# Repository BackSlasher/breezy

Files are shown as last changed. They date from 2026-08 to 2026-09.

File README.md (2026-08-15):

# Breezy

ESP32 smart-home component for my air conditioner, physically sitting between the HVAC controller and its LCD control panel.

The kit here is a **USP 5010** — controller plus LCD panel (the panel is
marked USP5010BE). If that is what you have, the protocol docs and the
ESPHome components in this repo should work as-is.

Smart-home capability achieved with ESPHome (flashed via USB, OTA available).  
Reads are done by intercepting SPI updates from the AC to the panel.  
Writes are done by emulating IR remote commands.

## In this repo
1. [pcb](pcb/): Board schematics, JLCPCB-ready
2. [esphome/components](esphome/components/): Custom ESPHome components ([example config](esphome/breezy_v4.yaml))
3. [case](case/): scad files for a small case/box for the pcb
4. [docs](docs/): the protocol specs — [the bus](docs/PROTOCOL_BUS.md) and
   [the IR command language](docs/PROTOCOL_IR.md) — plus the working notes
   behind them, and [some photos](docs/photos.md).

## Wiring

Physical wiring:
1. JST 6-wire cable (only 5 actual wires) to AC unit
2. JST 6-wire cable (only 5 actual wires) to LCD panel
3. 220v in (L/N screw terminals) for powering the ESP32 (5v from SPI is weak)

JST wiring is 5v (5v+, gnd, SPI data, SPI clock, IR)

The ESP32 itself is a socketed 38-pin ESP32-WROOM-32 DevKitC-style module
(2×19 headers) — not included on the PCB, plug in your own.

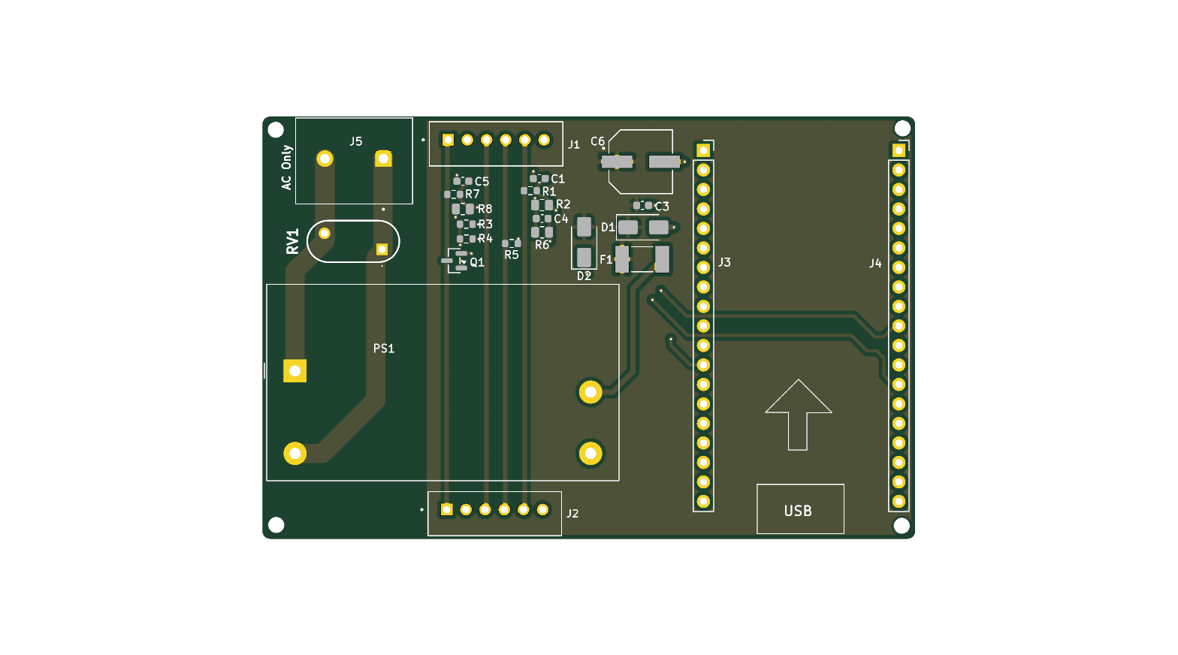
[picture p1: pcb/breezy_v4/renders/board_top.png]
board top


## The protocol, briefly

### Read
The HVAC and its panel talk over a clocked two-wire bus, ~33 ms per cycle.
There are exactly two frames on it:

- a **36-bit LCD status poll** — the controller opens it and goes quiet, and
  the panel answers *inside the same frame* by pulling bits low (the line is
  wired-AND). I don't decode what the panel says; I have no use for it.
- a **76-bit controller status** — the complete unit state, and the one I
  read: power, mode, set temperature, room temperature, fan speed, and
  whether the compressor is actually running right now.

Every bit of the controller status is located and its encoding known, so a
frame can be generated from scratch and checked against the two checksums it
carries. Two flag bits are still unexplained — I know where they are and
when they fire, just not what they mean; one is probably the panel's
backlight. Full field map in [`docs/PROTOCOL_BUS.md`](docs/PROTOCOL_BUS.md).

### Write

The controller is receiving IR commands from a remote via the LCD panel.
The panel holds an IR receiver, demodulates the output and sends the binary on a dedicated wire to the controller, which we can both intercept and send our own.

The IR protocol is reverse engineered completely: any mode, temperature and
fan speed can be composed from scratch, including power-on, which carries the
target state inside the toggle so the unit wakes straight into it. Full spec
in [`docs/PROTOCOL_IR.md`](docs/PROTOCOL_IR.md).

Two things about it are worth knowing before you read anything else:

- **The symbol spelling is the code.** Three of the four pulse shapes mean
  "1", so the same bits can be spelled several ways — and the unit treats
  different spellings as *different commands*.  
  When encoding / decoding, take care to note the length of each part of the pulse (the "on" and the "off" afterwards).
- **24 °C and 25 °C share a temperature byte** and are told apart only by the
  frame being one bit shorter. That one confused me for a while.

## Short version history

Bus pirate worked out of the box for reading, and Arduino R4 bitbanging was enough for writing.  
When moving to dedicated ESP32+PCB, I had to iterate a bit.  
My main pain points were:
1. HVAC wiring didn't contain enough current to power the ESP32, so I needed an external supply and converter
2. HVAC wiring was 5v, and ESP32 operates on 3.3v, so couldn't connect them directly and had to step voltage up/down

- **v1** — BSS138 level shifters with 10K pull-ups. Too slow for the bus; edges rounded off.
- **v2** — TXS0104 shifter, and the board's 5V tied to the panel's,
  either drawing too much current from the panel for it to work,
  or polluting the data with noise from the converter.
- **v3** — 5V properly isolated, but the TXS0104 turned out to be the wrong tool, occasionally misreading the ESP32 as low-driving and pushing that low to the HVAC side, making the panel get garbage data and display nonsense (−9 °C) whenever the ESP32 was powered. It also couldn't read
  and write IR on the same line.
- **v4** — replaced the TXS0104 with plain resistors (high-impedance 100K/180K
  divider taps for reading), and split IR across two ESP32 pins: one read-only
  via a tap, one write-only via an open-collector transistor that pulls the line
  low. For the HVAC components, the board feels like a plain cable.

A recurring pattern was that ESP32 was not a reliable narrator when it had other duties.  
I had several mysteries caused by the ESP32 doing something else (IR transmission, verbose logging) that occupied it enough so it missed bits, generating corrupt or odd frames, both making understanding current state much harder.   
If the measurement is weird, use a dedicated device (another esp32, BusPirate etc)

## ⚠ Mains voltage

This board is powered directly from **220 V AC** through screw terminals on the
PCB. It is a hobby project, not a certified appliance — it has had no safety
testing or approval of any kind. In particular, note it has **no mains-side
fuse**: F1 is a resettable PTC on the 5 V output, and the varistor sits
unfused across L–N. If you build one, you are responsible for
knowing how to work safely with mains, for enclosing it properly, and for
whatever your local regulations require. Don't work on it energised.

## License

MIT — see `LICENSE`.

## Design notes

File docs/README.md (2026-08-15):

# Docs

## Current

- [`PROTOCOL_BUS.md`](PROTOCOL_BUS.md) — the controller ↔ panel bus of a
  USP 5010. Two frame types, the complete field map of the state record,
  and the two checksums that authenticate a frame.
- [`PROTOCOL_IR.md`](PROTOCOL_IR.md) — the IR command language the remote
  (and this board) speaks: symbols, framing, the code tables, and the
  encoder state machines.
- [`photos.md`](photos.md) — pictures of the thing.

The cable pinout that matters for building one is in the
[main README](../README.md#wiring) and the
[board spec](../pcb/BREEZY_V4_SPEC.md).

The two protocol specs are written to be implementable on their own, with
no history needed. **Where anything else disagrees with them, they win.**

## [`historical/`](historical/) — superseded working notes

Raw engineering notes, kept because they show how the conclusions were
actually reached, and published close to unedited. Do not build on them:

- they reference scripts, capture files, hostnames and tooling from the
  development environment that are **not in this repository**;
- earlier notes were not rewritten when later work overturned them —
  supersession is marked in place, but several conclusions in them are
  simply wrong;
- much of the early work was done downstream of the USP5020 splitter,
  which serves a padded variant of the bus, so frame lengths and framing
  details there do not match the direct tap.

| file | what it is |
|---|---|
| [`historical/protocol_dump.md`](historical/protocol_dump.md) | the original bus reverse engineering, through the splitter. Its byte-2 field map was right on the first try and got re-derived the hard way months later |
| [`historical/IR_ENCODING.md`](historical/IR_ENCODING.md) | the first symbol-grammar write-up. Its power-frame section is superseded by `PROTOCOL_IR.md` §5 |
| [`historical/ir_commands.md`](historical/ir_commands.md) | the IR lab notebook: verified byte tables, raw captures, and a running record of what got retracted |
| [`historical/wires.md`](historical/wires.md) | wire colours mapped to signals, from the bench rig (extension cables, Bus Pirate hookup) |

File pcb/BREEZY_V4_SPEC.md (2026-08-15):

# Breezy PCB v4 Specification (rev 4.1, 2026-07-05)

> Internal full spec (rev history, design math, firmware notes). The vendor-facing
> derivative is `pcb/breezy_v4_pitch/` — README (cover), CHANGES (lean work order),
> TECHNICAL_APPENDIX (rationale). Those three intentionally omit internal context;
> keep them in sync with this file on substantive changes.

## Summary

ESP32-based AC controller that sits between an air conditioner and its LCD panel.
Reads SPI signals (CLK, DATA) and sends/receives IR commands.

**Critical change from v3:** Remove the TXS0104 level shifter entirely. It is a
pass-gate device — attaching it to the lines actively drives them and corrupted the
passthrough. v4 reads the lines through high-impedance resistor dividers and injects
IR through a single open-collector transistor. Nothing else touches the lines.

> Rev 4.1 supersedes the earlier v4 draft: divider topology corrected (series resistor
> FIRST, shunt at the GPIO), values raised 10K/10K → 100K/180K (threshold margin + bus
> loading), RC filters moved out of the passthrough, MMBT2222A instead of 2N7000,
> onboard IR receiver and board 3.3V regulator removed. Rationale: `pcb/V4_DESIGN_REVIEW.md`.

## Design Principles

1. **J1 and J2 connect directly** — six bare traces, no components of any kind in the path
2. Nothing attached to the lines may be able to drive them: reads are via **high-impedance
   resistor dividers** (280K per line), IR injection via one open-collector transistor
3. IR TX and IR RX use **separate GPIOs**
4. Keep 5V isolation from v3

---

## JST Connector Pinout (unchanged from v3)

Both J1 and J2, viewing connector with latch on top, left to right:

| Pin | Signal | Notes |
|-----|---|---|
| 1 | IR | IR signal line |
| 2 | GND | Ground |
| 3 | 5V_PASS | Passthrough only, NOT connected to board 5V |
| 4 | DATA | SPI data |
| 5 | CLK | SPI clock |
| 6 | NC | Dead/unused, rightmost |

---

## Signal Path Architecture

### Passthrough (J1 ↔ J2)

**CRITICAL: Direct connection. No components in the path — also remove the v3 in-path
RC filter (100R + 100pF) from the CLK line.**

```
J1 Pin 1 (IR)   ────────────────── J2 Pin 1 (IR)
J1 Pin 2 (GND)  ────────────────── J2 Pin 2 (GND)
J1 Pin 3 (5V)   ────────────────── J2 Pin 3 (5V)    ← NOT connected to board 5V
J1 Pin 4 (DATA) ────────────────── J2 Pin 4 (DATA)
J1 Pin 5 (CLK)  ────────────────── J2 Pin 5 (CLK)
J1 Pin 6 (NC)      (unconnected)   J2 Pin 6 (NC)
```

Pin 6 (NC): unconnected on both connectors, attached to no board net. Originally
specced as passed-through ("board = plain cable"), but the delivered v4 (2026-07-21)
left it open and this was accepted as-built: the LCD's white cable has no conductor
in position 6 (`wires.md`), so open vs. passed-through are electrically
indistinguishable on this system, and open matches the v3-era rule.

### Signal Taps (CLK, DATA, IR_RX)

One divider per line. **Orientation matters: the 100K series resistor sits between the
line and the GPIO node; the 180K and 100pF go from the GPIO node to GND.** (Do NOT put
the shunt on the line side — that would put 5V on the GPIO and load the bus.)

```
CLK line ──[100K]──┬────────── ESP32 GPIO14 (CLK_3V3)
                   │
             [180K]│[100pF]
                   │
                  GND

DATA line ──[100K]──┬───────── ESP32 GPIO27 (DATA_3V3)
                    │
              [180K]│[100pF]
                    │
                   GND

IR line ──[100K]──┬─────────── ESP32 GPIO5 (IR_RX)
                  │
            [180K]│[100pF]
                  │
                 GND
```

Resistors 1%. Design math (for review, not for "optimization"):

- **Levels:** 5.0V line → 3.21V at pin; 4.5V → 2.89V. ESP32 VIH is 0.75 × 3.3V =
  **2.475V** (datasheet — NOT the 2.0V TTL figure), abs max 3.6V. Margin on both sides.
- **Loading:** 280K per line — invisible even to a weak driver (a 30K-pull-up IR
  receiver output sags < 0.5V; a push-pull MCU pin doesn't notice at all).
- **Bandwidth:** ~64K Thevenin × ~110pF ≈ 7µs time constant vs a 71µs half-period at
  the 7kHz SPI clock. Edges settle in ~20µs; sampling is mid-bit. The 100pF doubles as
  the glitch filter that used to sit in the passthrough.
- **Fault isolation:** any ESP32 pin state (boot glitch, firmware bug, pin driven low)
  injects at most ~50µA into the line through the 100K. An unpowered ESP32 back-powers
  at µA level. The board physically cannot disturb the AC↔LCD link.

Acceptable substitutions: shunt anywhere in 150K–220K (target 2.9–3.4V at the pin from
the measured line-high voltage).

### IR TX Driver

Open-collector NPN pulls the IR line low to inject marks. The line's own pull-up
(inside the AC/panel) provides the high level — the board never drives the line high.

```
IR line ─────┬────────────── (continues to J2)
             │
         [collector]
             │
GPIO4 ──[1K]─┤ MMBT2222A
             │[base]
       [10K] │
             │[emitter]
            GND
```

- 1K base resistor from GPIO4; **10K base-to-GND pulldown** (holds the transistor off
  during ESP32 boot/reset)
- GPIO4 HIGH → transistor ON → line LOW (mark). GPIO4 LOW → transistor off → line
  floats, passthrough undisturbed (leakage < 1µA)
- IR protocol is active-low (TSOP-style): line idles HIGH, marks are LOW. The
  transistor inverts, so firmware drives GPIO4 HIGH for marks.
- Part: MMBT2222A (SOT-23). Acceptable alternates: BSS138 or AO3400 with the 10K as a
  gate pulldown (100K also fine for a FET). **Do NOT substitute 2N7000/2N7002** — its
  gate threshold is specced up to 3.0V, marginal from a 3.3V GPIO.

---

## Power

- 220V AC input via screw terminals; fuse (F1) and varistor (RV1) unchanged
- Hi-Link IRM-10-5 AC-DC converter → +5V_BOARD
- +5V_BOARD → **SS14 Schottky diode** → ESP32 DevKit VIN (the diode prevents contention
  if USB is plugged in while the board is mains-powered)
- **Remove the AMS1117-3.3 and its caps** — with the TXS0104 gone, nothing on the board
  uses 3.3V; the DevKit regulates its own. The DevKit 3V3 header pin connects to
  NOTHING (do not tie it to any board rail).
- 5V isolation unchanged from v3: J1 pin 3 ↔ J2 pin 3 only; +5V_BOARD is a separate net;
  the two must not connect anywhere.

---

## Component Changes from v3

| Remove | Add |
|---|-----|
| TXS0104 level shifter + its 2× 100nF bypass caps | 3× 100K 1% (series taps) |
| Onboard IR receiver (IR2) + its resistor | 3× 180K 1% (shunts) |
| AMS1117-3.3 + its caps | 3× 100pF (tap filters) |
| In-path CLK RC filter (100R + 100pF) | 1× MMBT2222A (SOT-23) |
| | 1× 1K + 1× 10K (base network) |
| | 1× SS14 (VIN feed) |

The onboard IR receiver is redundant: the LCD panel contains the system's IR receiver
and the board taps its output line (that is what GPIO5 reads). Leaving it connected to
GPIO5 would short its output into the divider.

---

## ESP32 GPIO Assignments

| GPIO | Signal | Direction | Notes |
|---|---|---|---|
| GPIO14 | CLK_3V3 | Input | no internal pull-up (see firmware notes) |
| GPIO27 | DATA_3V3 | Input | no internal pull-up |
| GPIO5 | IR_RX | Input | no internal pull-up |
| GPIO4 | IR_TX | Output | drives transistor base; HIGH = mark |

### Firmware notes (not for the PCB designer)

- Internal pull-ups/downs on GPIO14/27/5 must stay disabled — a ~45K internal pull-up
  against a 280K divider pins the reading. ESPHome's plain `INPUT` mode is correct.
- `remote_receiver`: pin GPIO5, `inverted: true` (line is active-low).
- IR send: mark → GPIO4 HIGH, idle → GPIO4 LOW. The v2 `send_ir_raw` lambda convention
  becomes correct through the inverting transistor **as-is** (its polarity was inverted
  for the v2/v3 non-inverting TXS path — likely why v3 commands weren't accepted).
- Boot-time pull-ups on GPIO14/GPIO5 are isolated from the lines by the 100K series
  resistors; no action needed.

---

## Mechanical

- Keep v3 dimensions (80 × 55mm) and mounting/connector positions if convenient —
  the printed case/tray (`case/*.scad`) fit them but can be reprinted.

## Unchanged from v3

- ESP32 DevKit socket footprint and orientation markers
- Screw terminals for 220V AC input, fuse F1, varistor RV1
- JST pinout (Pin 1 = IR, Pin 6 = NC)
- 5V_PASS isolation

---

## Deliverables Needed

- KiCad project (schematic + PCB source files)
- Gerber files for JLCPCB
- BOM and pick-and-place files for JLCPCB assembly (LCSC part numbers)

---

## Checklist for Designer

Before sending files:

- [ ] J1 and J2 pins 1–5 connect directly — no components in any passthrough trace
      (the old CLK RC filter is gone too); pin 6 unconnected
- [ ] 5V_PASS net connects J1-pin3 to J2-pin3 and nothing else
- [ ] Divider orientation: 100K from line to GPIO node; 180K and 100pF from GPIO node
      to GND (never the shunt on the line side)
- [ ] Transistor: collector to IR line, emitter to GND, 1K from GPIO4 to base, 10K base
      to GND
- [ ] TXS0104, onboard IR receiver, AMS1117 all removed; DevKit 3V3 pin unconnected;
      VIN fed via SS14 from +5V_BOARD
- [ ] GPIO map: 14 = CLK, 27 = DATA, 5 = IR_RX, 4 = IR_TX
- [ ] Print 1:1 and verify JST connector fits cable correctly

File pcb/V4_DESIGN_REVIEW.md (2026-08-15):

# v4 Spec Design Review (2026-07-05)

Review of `BREEZY_V4_SPEC.md` (pre-revision), the v3 as-built schematic (nets extracted
from the v3 EasyEDA project), v3 testing notes, and the firmware on both sides of
the IR path. Findings below are incorporated into the revised spec (v4.1). Confidence
ratings are honest: "certain" = internal contradiction or datasheet fact; "high" =
arithmetic with wide margins; "medium" = plausible but unverified on hardware.

## Findings

### F1. Divider diagram drawn wrong (critical — certain)
The tap drawings in the original v4 spec placed the shunt resistor on the passthrough
line and the series resistor between junction and GPIO. Built literally: a high-Z input
draws no current, so the GPIO sees the **full 5V** (ESP32 abs max is 3.6V — not 5V
tolerant), and the bus gets a hard 10K-to-GND load. The text ("gives ~2.5V") contradicted
the drawing. Fixed: series resistor first, shunt at the GPIO node.

### F2. 10K/10K ratio sits on the input threshold (critical — certain on the datasheet, high on practical failure)
The spec claimed "ESP32 reads HIGH > 2.0V". The datasheet says VIH = 0.75 × VDD3P3 =
**2.475V** at 3.3V. A 2.5V tap has 25mV margin — erased by resistor tolerance or the AC's
5V rail sagging (a rail already known to be weak). Fixed: 100K/180K → ~3.2V at the pin.

### F3. 20K bus loading is risky on weakly driven lines (high — high)
CLK/DATA driver strength is unknown; the IR line is almost certainly weak (TSOP-style
receiver outputs typically have ~30K internal pull-ups — a 20K tap would drag the idle
level to ~2V and break the real remote *through* the board). Fixed: 280K total tap
impedance, invisible even to a 30K source. Bonus: any ESP32 pin fault (boot glitch,
firmware bug, output-low) can inject at most ~50µA into the bus through the 100K series
resistor, and an unpowered ESP32 back-powers at ~µA level — both harmless.

### F4. 2N7000 is a gate-drive lottery at 3.3V (medium — certain on the spec)
2N7000 VGS(th) is specced up to 3.0V; driving it from a 3.3V GPIO is worst-case-part
roulette. Fixed: MMBT2222A with 1K base resistor (deterministic at 3.3V), 10K base
pulldown to hold it off during boot. BSS138/AO3400 acceptable alternates; 2N7000 rejected.

### F5. Onboard IR receiver collides with GPIO5 (high — certain from v3 netlist)
The v3 board has an onboard IR receiver (IR2, net `IR_RECEIVE`) wired to GPIO5. The v4
spec reassigned GPIO5 to the IR-line tap without mentioning the receiver — an
edit-in-place designer would short the receiver output into the divider. It is redundant
(the LCD panel is the IR eye; we tap its line). Fixed: explicit removal.
### F6. Dual-LDO conflict carried over from v2/v3 (low-medium — high)
v2/v3 fed both the DevKit's VIN (5V) and its 3V3 pin (from the board AMS1117) — two LDO
outputs tied together. With the TXS gone, nothing on the board needs 3.3V. Fixed: remove
the board AMS1117; feed VIN only; 3V3 header pin left unconnected.

### F7. RC filters don't belong in the shared path (low — high)
The noise being filtered corrupts the *reader*, not the LCD — which ran for years on the
raw signal. Filtering moved to the tap side (100pF at the GPIO node); passthrough is six
bare traces; v3's in-path 100R/100pF on CLK removed. Also fixes a math nit: 100R×100pF is
a ~16MHz corner, not the ~1.6MHz claimed in the v3 requirements.

### F8. v3 IR TX failure was probably firmware polarity, not hardware (medium-high; the mismatch itself is certain)
The proven-working Arduino sketch (`arduino/ac_ir.ino`) idles the line HIGH and sends
marks as LOW. The ESPHome `send_ir_raw` lambda in `esphome/breezy_v2.yaml` does the exact
inverse (idle LOW, mark HIGH) through a non-inverting shifter — consistent with "backlight
wakes but commands not accepted". v4's transistor stage inverts, so the existing lambda
convention (mark → GPIO HIGH → line LOW) becomes correct unchanged. Testable for free on
the v3 board (firmware-only reflash) any time before v4 arrives.

### F9. USB-while-mains hazard on VIN (low — certain)
The DevKit has no diode between USB 5V and VIN; plugging USB while the board is
mains-powered ties the two 5V sources. Existed in v2/v3 too. Fixed: SS14 Schottky in the
+5V_BOARD → VIN feed.

## Why v3 actually failed (mechanism, refined)

The v3 netlist shows single `CLK`/`DATA` nets: J1↔J2 were already directly connected, and
the TXS0104 was *attached* as a tap — the testing-notes theory ("signals go through the
shifter") was topologically wrong, but the conclusion was right, because the TXS0104 is a
pass-gate device: each B pin couples to its A pin through a pass transistor, with ~10K
internal pull-ups on both ports and one-shot edge accelerators that actively drive the
lines. Attaching it to a bus is never passive. It wired the ESP32's pin states onto the
5V bus (hence corruption only with the ESP32 socketed: boot-time pulls, pin modes, and a
second paralleled LDO on VCCA all arrive with the DevKit), and its internal pull-ups
quietly re-coupled the AC's signal lines to the board's 5V rail — bypassing the pin-3
isolation v3 got right. The v4 rule is therefore not "nothing between J1 and J2" but
"nothing attached to the lines that can drive them"; resistor dividers satisfy it.

## Residual risks after v4.1 (and why they're acceptable)

1. **Unknown bus driver topology.** Mitigated by 280K taps; worst case is a misread, not
   damage, and shows up immediately on first power-up with the LCD as the witness.
2. **IR protocol subtleties** (timing drift, frame format). The hardware bakes in no
   protocol assumptions — taps plus an open-collector pull-down — so every failure of
   this class is firmware-iterable using the board's own RX tap (capture the real remote
   through the actual panel path, replay, compare).
3. **No bench validation before fab** (no parts on hand, no soldering). Accepted: values
   were chosen so that being wrong is cheap, and the two free v3 firmware tests (polarity
   reflash; EN-held-low LCD observation) remain available while boards are in transit.

## Recommendations

- Convert to KiCad at this revision (major rev anyway — the central IC is removed and a
  dozen parts added). Text-format sources allow machine verification of the delivered
  design: netlist assertions against the designer checklist plus `kicad-cli` ERC/DRC,
  before JLCPCB sees gerbers.
- Verify the delivered files rather than buying a design review. The changed circuitry is
  six resistors, three caps and one transistor with wide margins; the historically
  expensive errors (v2 reversed pinout, v2 tied rails, v3 active tap) were all
  execution-level, which file verification catches. If extra human eyes are wanted, a
  one-page schematic gets real scrutiny for free on EEVblog or r/AskElectronics.

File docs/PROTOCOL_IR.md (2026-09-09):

# The IR Command Language - Clean Reference

Current-truth spec of the command protocol the remote (and breezy) sends to
the HVAC controller of a **USP 5010** kit, validated on the permanent
install (2026-08-14). Written top-down:
messages -> serialization -> wire. History lives in `ir_commands.md`; the
bus that reports state back is `PROTOCOL_BUS.md`.

## 1. Message model

There are exactly **two message types**, and both carry the same payload:

```
STATE_COMMAND (mode, fan, temp)   # "set the running unit to this"
POWER_FRAME   (mode, fan, temp)   # "toggle power; apply this on wake"
```

| field | domain |
|---|---|
| mode | heat, cool, fan_only |
| fan  | auto, low, med, high |
| temp | 16..30 (°C) |

Semantics:

- **STATE_COMMAND** applies mode/fan/temp to a running unit. An OFF unit
  ignores it completely.
- **POWER_FRAME** toggles power. There is no discrete on or off message -
  the remote holds no power state, and neither can you. When the toggle
  lands as power-ON, the unit wakes *directly into* the embedded
  (mode, fan, temp). When it lands as power-OFF, the payload is stored but
  the unit just turns off.
- Therefore: wake a known-off unit with ONE power frame carrying the target
  state; never blind-retry a power frame (a re-sent toggle un-does the
  first - verify against the bus first).

**Relationship between the two types**: think of POWER_FRAME as
STATE_COMMAND plus a 1-bit "and toggle power" flag - except the flag lives
in the header timing (section 3.3), not the payload. Putting the one
destructive bit in a gross timing difference (repeated at both separators)
makes it essentially impossible for noise to turn a temp change into a
power toggle. The two types also use different CODE tables for the same
(mode, fan) - see section 2.

There is no reply channel in IR. The unit beeps on accept (~always, within
~1s); actual state feedback comes from the bus (`PROTOCOL_BUS.md`).

## 2. Serialization: message -> bits

Both message types serialize to the same 30-31 bit frame body:

```
+----------------+----------------+----------+---------------+
| CODE(mode,fan) | TEMP(temp)     | 00000000 | TAIL          |
| 7-8 bits       | 8 bits         | 8 bits   | 6-7 bits      |
+----------------+----------------+----------+---------------+
```

The message TYPE is not in the bits - it's carried by the frame header
timing on the wire (section 3.3).

**TEMP** - lookup table, MSB first:

| °C | byte | | °C | byte | | °C | byte |
|----|---|-|----|---|-|----|---|
| 16 | `0C` | | 21 | `28` | | 26 | `74` |
| 17 | `18` | | 22 | `24` | | 27 | `50` |
| 18 | `14` | | 23 | `60` | | 28 | `5C` |
| 19 | `30` | | 24 | `78` | | 29 | `48` |
| 20 | `3C` | | 25 | `78` | | 30 | `44` |

**TAIL** = `0000011`, except `000011` (6 bits) when temp = 24 - though that
bit-level description is a projection artifact: on the wire, 24°C's temp
word is `0x78` re-spelled at identical duration and the frame's END is
trimmed to pay for it. 24°C and 25°C share `78` and are distinguished by
spelling alone. See section 3.5 (the isochrony law) for what is actually
going on.

**CODE** - for STATE_COMMAND the code is a byte (with ONE exception, below).
DRY and AUTO are documented for completeness but unsupported by breezy;
blank cells are fan speeds the remote refuses in those modes:

| fan  | heat | cool | fan_only | AUTO | DRY |
|---|---|---|---|---|-----|
| auto | `74` | `24` | `E4` | `44` | - |
| low  | `60` | `30` | `F0` | `50` | `C0` |
| med  | (7-bit) | `3C` | `FC` | `5C` | - |
| high | `78` | `28` | `E8` | - | - |

**The byte codes are COMPOSITIONAL** (confirmed 2026-08-14 by capturing
DRY/AUTO): `code = mode_base<<4 | fan_nibble | parity`. Fan nibbles:
auto=`4`, low=`0`, med=`C`, high=`8` - exact across all modes. Mode bases:
cool=`2`, AUTO=`4`, heat=`6`, DRY=`C`, fan_only=`E`. Bit `0x10` is set
when needed to make the byte's popcount EVEN. Every entry above derives
exactly (e.g. AUTO/low = `40`, odd popcount, `|0x10` -> `50`).

**The apparent exception - heat/med reads as 7 bits** (2026-08-14 capture,
live validated): its code is `0111100`, spelled `SS LS LM LS LM SS SS`.
At the bit level this looks like heat/high truncated by one bit; on the
wire it is heat/high's word (`0x78`) RE-SPELLED AT IDENTICAL DURATION -
same trick as 24°C-vs-25°C, and nothing is actually shorter. See section
3.5: the heat mode only has 3 legal 18-tick words for its 4 fan speeds,
so `0x78`'s unique alternate spelling plugs the gap. The historic `5C`
"heat/med" table entry was a mislabeled AUTO/med capture (`5C` = `4C|0x10`
per the composition; sending `5C` to a unit in heat was observed live to
switch it out of heat into a mode whose bus code is `00` - by elimination,
AUTO). With that relabel, and the isochrony law, the vendor table contains
NO anomalies at all - every entry derives.

For POWER_FRAME the code is 7-8 bits and - critically - is defined at the
SYMBOL level, not the bit level. See the wrinkle below.

## 3. Wire encoding: bits -> pulses

### 3.1 The alphabet, and the wrinkle

The wire alphabet is four pulse-distance symbols (baseband on the IR line,
idle high, mark = line low; timings in µs, remote-matched):

| symbol | mark | space | reads as bits |
|---|---|---|---|
| SS | 1024 | 894  | `0`  |
| LS | 1024 | 1854 | `1`  |
| LM | 1992 | 894  | `1`  |
| LL | 1992 | 1849 | `11` |

The names are not positional pairs. `L` says the symbol is long overall, and
the second letter says which half is stretched: `M` = the **mark**, `S` = the
**space**. So `LS` is a short mark with a long space, and `LM` is its mirror.
There is no "medium" anywhere in the protocol - every part is short or long.

Three different symbols encode `1`s, so one bit string has many possible
"spellings" - and **the receiver distinguishes commands by spelling, not
bits**. Example: heat/med and cool/med power codes are both `1111100` as
bits, but heat spells it `LL LM LS LM SS SS` and cool spells it
`LM LS LL LM SS SS` - different commands.

Consequences, and they are asymmetric:

- **Encoding**: reproduce spellings exactly. Right bits in the wrong
  spelling are silently ignored - no beep, no reaction, indistinguishable
  from not transmitting at all.
- **Decoding**: collapsing symbols to bits is LOSSY AND UNSOUND. It happens
  to identify most commands uniquely, which is why a bit-level decoder can
  appear to work for a long time, but the heat/med and cool/med power codes
  genuinely collide - no bit-level decoder can tell those two apart. Decode
  to the symbol sequence and compare that.

### 3.2 Spelling rules

The TEMP/zeros/TAIL region is always spelled by the `Standard` state
machine below. The CODE region:

- STATE_COMMAND codes: spelled by a state machine over the whole frame -
  `Standard` for heat, `LsStart` for cool/fan_only.
- POWER_FRAME codes: verbatim symbol strings (the code IS the spelling):

| fan  | heat | fan_only | cool |
|---|---|---|---|
| auto | `LL LL SS LM SS SS` | `SS LL SS SS LM SS SS` | `LM LS SS SS LM SS SS` |
| low  | `LL LM SS SS SS SS SS` | `SS LL LM SS SS SS SS` | `LM LS LM SS SS SS SS` |
| med  | `LL LM LS LM SS SS` | `SS LL LL LM SS SS` | `LM LS LL LM SS SS` |
| high | `LL LL LM SS SS SS` | `SS LL SS LM SS SS SS` | `LM LS SS LM SS SS SS` |

after which the rest of the frame continues on the `Standard` machine,
seeded with the state the code symbols left behind.

The `Standard` machine (states `Fresh`, `After0`, `AfterLL`, `AfterLM`,
`AfterLS`), consuming bits:

- `0` -> emit SS. Fresh->AfterLM; AfterLL/AfterLS->After0; else unchanged.
- `1` followed by `1`, from any state except AfterLM -> emit LL (consumes
  both bits).
- `1` otherwise: from Fresh -> LS; from After0/AfterLS/AfterLL -> LM.
- `1` from AfterLM -> LS, always (this is why tails end `... LS LM`).

`LsStart` is identical except LL is not allowed from `Fresh`.

Net effect: isolated `1`s alternate LS/LM through the frame; runs of `1`s
compress to LL pairs where the machine allows.

### 3.3 Framing: the blast

One transmission ("blast") is **three identical frames** - all three
required; 1- and 2-frame blasts are rejected - then a trailing mark:

```
[HDR][frame][SEP][frame][SEP][frame][TRAIL]
```

| element | mark (µs) | space (µs) |
|---|---|---|
| HDR / SEP, STATE_COMMAND | 2994 / 2953 | **~2813** |
| HDR / SEP, POWER_FRAME | 2994 / 2953 | **~3773** |
| TRAIL | 3980 | (idle) |

The header/separator SPACE is the message-type discriminator - same body
bits with the ~3773µs spacing is a power frame.

### 3.5 THE ISOCHRONY LAW (2026-08-17) - time, not bits, is the unit

Every symbol is an exact integer multiple of one ~960µs tick:

| symbol | duration | reads as |
|---|---|---|
| SS | 2 ticks | `0` |
| LS | 3 ticks | `1` |
| LM | 3 ticks | `1` |
| LL | 4 ticks | `11` |

**Every state-command frame is exactly 68 ticks** (code word 18 + temp word
18 + zeros/tail 32), across 123 archived capture arrays and every live
frame checked. Bit counts wobble 29-31; duration never moves. Power-frame
code words are 17 ticks (odd parity - the two message types are
parity-separated) and the power header space is exactly one tick longer,
keeping the blast total constant.

Consequences, each verified:

- **The "parity bit" is duration bookkeeping.** Even popcount == even
  duration; the `|0x10` rule in the code table is the bit-level shadow of
  "every word lasts an even number of ticks."
- **Both "7-bit" anomalies are the same object.** `LL` (4 ticks, reads
  `11`) can be re-spelled `LM LS` (6 ticks, reads `11`) and one trailing
  `SS` (2 ticks, reads `0`) dropped to pay for it: same duration, one bit
  fewer. `0x78` is the ONLY byte in the vocabulary where this substitution
  is legal - and the word inventory needed exactly that escape hatch
  exactly twice: 14 legal temp words exist for 15 temperatures (24/25
  share `78`), and 3 legal heat code words exist for 4 fan speeds
  (heat/med reuses `78`'s alternate spelling). Cool, AUTO and fan_only
  each have exactly 4 legal words for 4 speeds - no anomaly needed. DRY
  has exactly ONE legal word (`C0`, no alternate possible) - and the
  vendor remote indeed refuses every fan speed but one in DRY.
- **Wrong duration = rejection.** Live-tested 2026-08-17: heat/med sent as
  a 66-tick frame (identical BITS to the real one) is ignored; the 68-tick
  spelling lands first-try. This retroactively explains three historical
  rejections, all exactly 2 ticks short: fan-only-24 (byte0 `LL LL LL` =
  16 ticks vs the remote's 18), the heat/auto power frames of 2026-08-07
  (tail `LL` for `LS LM`), and the naive 24°C truncation.
- **Right duration is necessary, not sufficient**: heat/med and cool/med
  power codes are equal-duration, equal-bits, different-shape - and the
  receiver tells them apart. The best receiver model is a fixed-length
  sampling window feeding a waveform-template matcher.

Predictions if anyone extends the table: AUTO/high, if it exists, must be
`0x48` (the last unused word); no second DRY word can exist; and no
USP-style remote under this scheme can offer more than 15 temperatures.

## 4. Epistemics: what is fact and what is model

The layer cake in this document (messages -> bits -> symbols) is OUR
parser's abstraction; the wire truth is symbols, and the receiver's
internals are inferred. Notably, the "shared" temp/zeros/tail bits can
still be SPELLED differently between the two message types (the state
machine enters the temp region in whatever state the code region left it).
Evidence the receiver really decodes field-like structure rather than
matching whole memorized blasts: the encoding is compositional - we built
frames for (mode, fan, temp) combinations never present in any capture by
combining code spellings with temp bytes, and all tested combinations were
accepted first-frame. Evidence it does NOT work at the bit level: correct
bits in a wrong spelling are rejected. Best model: a per-family symbol
template matcher with a substitutable temp slot - consistent with remote
and receiver both being generated from the same authored waveform tables.

## 5. Implementer notes

- Acceptance is first-frame; beep = accepted. Verify by decoding the bus,
  wait ~2.5s, require a fresh reading before judging, back off on
  disagreement - and never blind-retry power frames (toggle parity).
- Your own blast echoes into your own receiver on the shared wire; expect
  ~0.5s of decode disruption and discard the echo.
- Transmit with hardware timing (RMT or equivalent) - bit-banged output
  glitches under multitasking and the receiver notices.

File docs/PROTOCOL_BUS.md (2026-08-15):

# The Controller <-> Panel Bus - Clean Reference

Current-truth spec of the wire protocol between the HVAC controller and the
LCD panel of a **USP 5010** kit (panel marked USP5010BE), as measured on the
permanent install (2026-08-14). No history - for how each fact was
established, see the working notes (`ir_commands.md`, and the bring-up
post-mortems where they are available). The IR command language (what the
remote and breezy transmit) is a separate document: `PROTOCOL_IR.md`.

## 1. Physical layer

```
HVAC controller ==== 6-wire cable ==== LCD panel
                     (breezy inline)
```

A clocked two-wire bus (CLK + DATA) plus 5V/GND and the IR line (see
`PROTOCOL_IR.md`). The panel PCB carries `isck`/`isda` silkscreen labels,
but it is NOT established that those pads connect to the cable's bus legs -
they may be a separate programming interface for the panel's chip.

**The DATA line is wired-AND (open-drain style).** The controller clocks
every frame; a party "writes" only by pulling bits low, and an unwritten
line reads as 1. Proven by unplugging the panel (2026-08-14): frame cadence
was unchanged, but every bit the panel used to write floated to 1. This is
why there is no such thing as a "reply" here - see section 2.

Breezy taps CLK/DATA read-only via interrupt, recording gap-delimited
bursts (>500µs idle delimits a burst).

## 2. Frame inventory - there are exactly TWO frames

| frame | bits | written by | carries |
|---|---|---|---|
| **LCD status poll** | 36 | 4-bit controller header `1001`, then 32 bits the PANEL pulls low | whatever the panel reports - believed to include keypresses (unverified) |
| **controller status** | 76 | controller only | the complete unit state + 2 checksums |

Both are clocked by the controller on a ~33ms cycle; a controller status
follows its LCD status poll after ~611µs.

The poll is a genuine poll, with an unusual twist: because the line is
wired-AND, the LCD's answer is written INTO the poll frame rather than
sent as a separate response. What the panel actually reports is NOT
established (section 2.1) - only the controller status has been decoded.

### 2.1 LCD status poll - PROVISIONAL, low priority

Not heavily researched, as I'm not reading / writing this.  
These are written by the panel, because when unplugged these are all "1"s.  
The panel's idle value (plugged in, not pressing anything) is `95 5F FF F1 5x`.

Unverified notes from a single session, don't blindly trust:

| key (claimed) | poll read (unverified) |
|-----|---|
| power | `95 50 F0 F5` |
| temp up | `95 52 F2 F4` |
| mode | `95 54 F4 F7` |
| fan | `95 58 F8 F3` |
| temp down | `95 5C FC F0` |
| (idle, panel absent) | `9F FF FF FF F0` |

Current hardware can't physically write these (DATA is read-only) and has nothing to do with keypresses.  
A possible redesign can support this if we come up with a reason.

## 3. Controller status - the complete state record

**Structurally complete** as of 2026-08-14: every bit's position and
encoding is known, so a frame can be generated from scratch and validated
by its own checksums. Two flag bits are located but their MEANING is not
identified (byte2 `0x04` and byte3 bit7 - see the table). Canonical length
is exactly **76 bits**; any other length is a capture defect (section 5).

`br4(x)` below = 4-bit reversal; this protocol transmits nibbles LSB-first.

| field | meaning |
|---|---|
| byte0-1 | header `60 00` |
| byte2 | **bitfield**: `0x08` power ON, `0x02` compressor running, `0x04` an unidentified flag that only appears alongside byte3 bit7 |
| byte3 | `00`, except bit7 - a transient that pulses for a median 1.9s (2.5% duty, 86% of it while ON, no compressor correlation): an indicator blink or command-ack, not a status bit. Suspected LCD backlight |
| byte4 | set temp: `br4(low nibble) + 16` |
| byte5 | fan: `80` auto, `84` med, `88` high, `8C` low |
| byte6 | mode: `20` heat, `80` cool, `C0` fan_only, `40` DRY, `00` AUTO. (DRY and AUTO not heavily tested) |
| byte7 low nibble + byte8 high nibble | **room temp**, one 8-bit field, LSB-first, biased by 40: `room = (br4(byte7 & 0x0F) \| (br4(byte8 >> 4) << 4)) - 40`. Matches an independent oracle exactly on 97.8% of denoised frames, within 1C on 99.99% |
| byte8 low nibble | **checksum 1** (section 3.1) |
| byte9 high nibble | **checksum 2**; byte9's low nibble is always 0 |

**The off-state mirror**: while the unit is OFF, bytes 4-6 keep reporting
the *stored* mode/set/fan (what the unit would wake into). Only byte2 tells
the truth about power. Never infer power from mode.

### 3.1 The two checksums

Read the 76 bits LSB-first as nineteen 4-bit groups; the last two are sums
of the preceding groups, mod 16. In byte terms:

```
br4(byte8 & 0x0F) == sum(br4(byte[i] & 0x0F) for i in 0..7) % 16
br4(byte9 >> 4)   == (sum(br4(byte[i] >> 4) for i in 0..7) - 2) % 16
```

The `-2` seed is constant across a 29h archive. Both hold on 99.87% of
denoised archive frames and 100% of clean live capture (91/91).

**Use them as the frame filter** - they are a true validity oracle, and
they replaced the structural guesses (byte3/mode/temp-range) that used to
reject legal frames and pass corrupt ones. One blind spot: the room field's
upper bits (byte8 high nibble) are covered by NEITHER checksum, so a bit
dropped there is invisible - keep a separate repeat vote on the room.

## 4. What the panel is

A dumb terminal. It answers the poll with its keypad state and renders the
controller status; it holds no state of its own, and the unit runs normally
with it unplugged.

## 5. Capture health - read before believing any capture

We used to have frames that are one bit short.
Turns out it's capture artifacts from keeping the ESP32 cpu busy with logging (40.5% corruption on VERBOSE logging, 0.1% on DEBUG).  
When in doubt, use the **throttled DEBUG sampler** (`sample:` log lines, <=2 bursts/s, verified 100% pure), never the VERBOSE dump.  
Alternatively, use a dedicated capture device (either another ESP32, or BusPirate).

**Bursts longer than 76 bits are two frames stuck together.** If you delimit
bursts on an idle gap (breezy uses >500µs), the ~611µs gap between a poll and
its controller status sometimes measures short and the pair arrives as one
111-114 bit burst - more often when the CPU is busy. Don't discard them: the
controller status starts at bit 37 (36-bit poll + 1) and passes both
checksums. Breezy un-glues them rather than dropping the frame.

## 6. Appendix: the splitter dialect

The AC ships an accessory "splitter" (**USP5020**) - a hub with one uplink
socket, one panel socket, and three sockets for dumb IR-eye/LED pods (an LCD
panel does not work on those). The permanent install does without it. It is not a protocol translator: downstream of it the
controller status keeps the same header and field offsets and merely gains a
padded tail (`... 55 FF FF 15`), a prefix-compatible superset that a
length-tolerant reader parses without knowing anything changed. Breezy
retains that grammar as `dialect: splitter`; the permanent install is
splitterless and uses `raw`. The pod protocol on the three remaining
sockets has never been tapped.

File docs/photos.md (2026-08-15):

# Photos

Some photos I made

## Looking at some boards

### USP5020 hub board
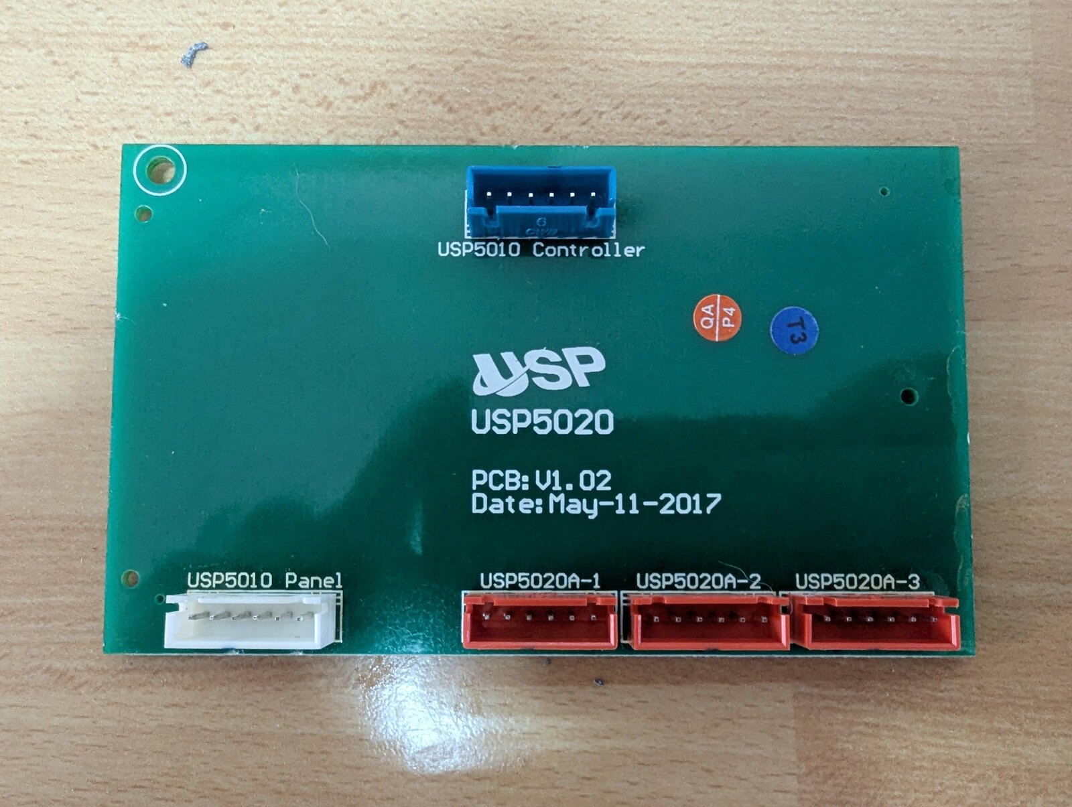
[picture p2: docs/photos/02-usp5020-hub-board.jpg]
USP5020 hub board
  
This is a side-board that allows "splitting" the lcd-port cable into one lcd-port and more "dumb" terminals that only include a status led and IR receiver.  
I was hoping that the splitter would allow me to connect my gizmo in parallel to the LCD screen and not between, but no, because the pins on the red JSTs don't map 1-1 to the blue/white pins.  
I now believe that there's a chip inside the splitter that extracts "led status" from the SPI messages, and passes IR messages upstream as is. In any case, I can't use this splitter for anything useful.

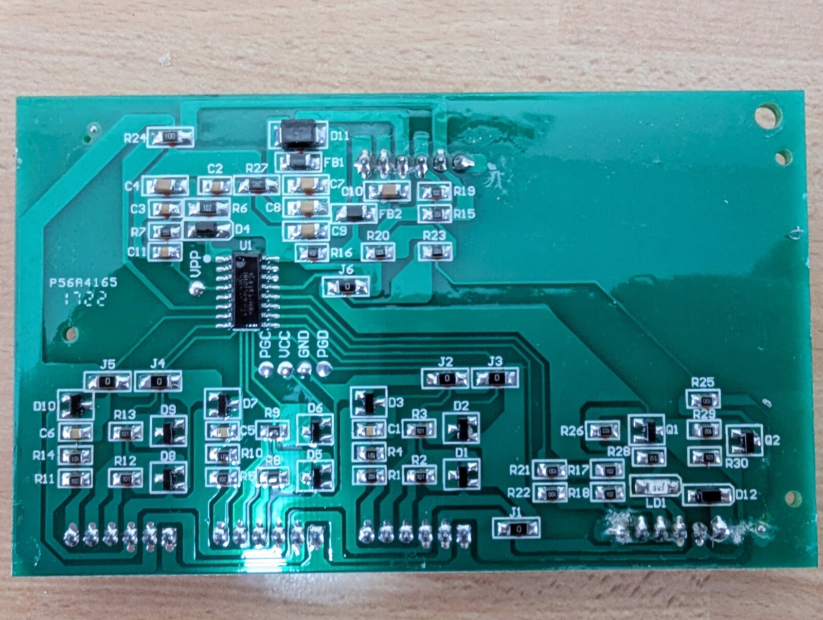
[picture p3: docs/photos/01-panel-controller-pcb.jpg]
HVAC panel controller PCB, solder side
  
From the other end.  
Note the 4 programming pads (PGC, VCC, GND, PGD). They're dead, probably cut after initial flashing, but it made me hopeful that the actual communication protocol also has a data/clock pair that I can tap

### Panel front, outside the plastic case
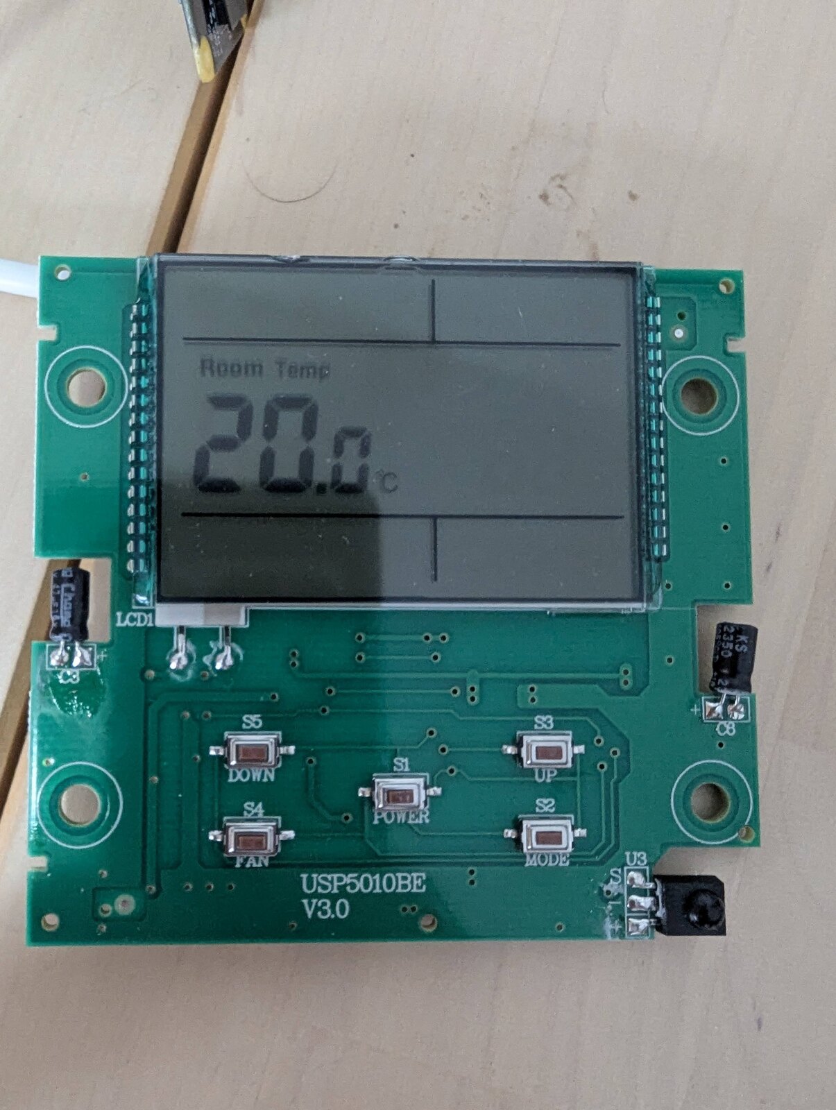
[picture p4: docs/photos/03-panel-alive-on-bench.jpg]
Panel front, outside the plastic case
  
Not very interesting. You can see the IR receiver on the bottom right. The PCB identifier gave me nothing when searching it online.

### Panel board in its housing with the harness attached
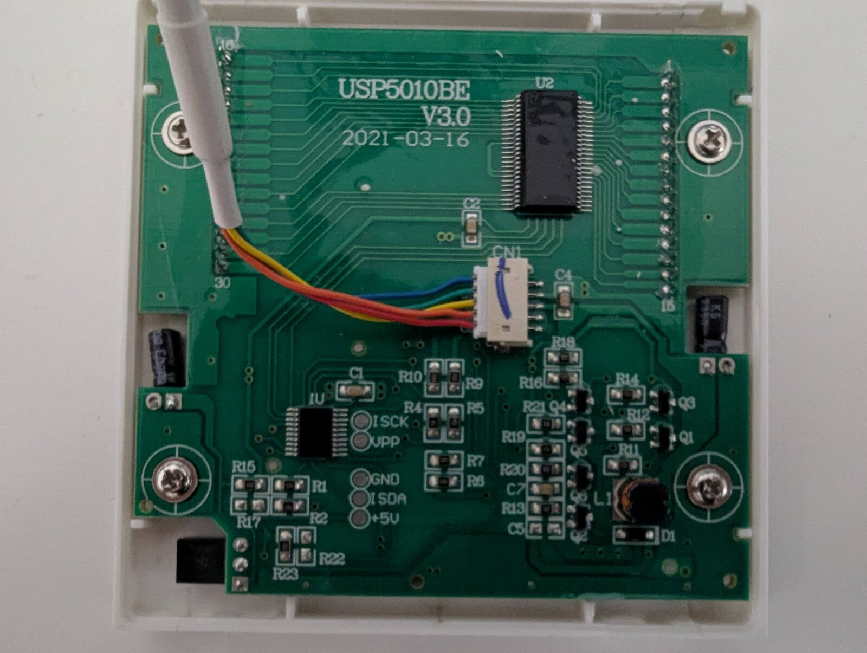
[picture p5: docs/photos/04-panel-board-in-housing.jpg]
Panel board in its housing with the harness attached
  
The backside of the LCD panel. None of the chips were recognizable, but using a multimeter on the pads (ISCK, VPP, GND, ISDA, +5V) and the different JST connectors hinted me on which color wire is which, and that one of the protocol's sides is ISP-shaped. 

## Buspirate and Arduino

### Bus Pirate probing the bus
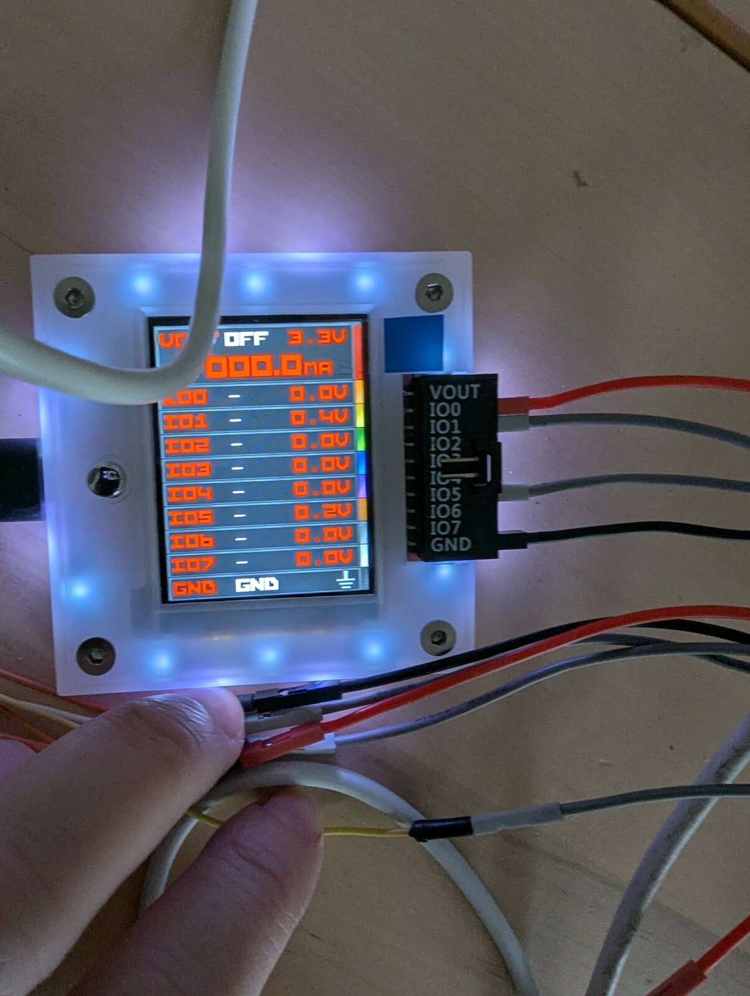
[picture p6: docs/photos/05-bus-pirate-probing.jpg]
Bus Pirate probing the bus
  
This was after I cut the AC controller-panel cable and connected it to the buspirate directly. You can see some wires have some voltage, which means something is working.  
Fun fact: I initially connected the wrong wires to gnd/5v+, meaning that about 2 days of sniffing were wasted on bad results.

### Camera + Bus Pirate correlation rig
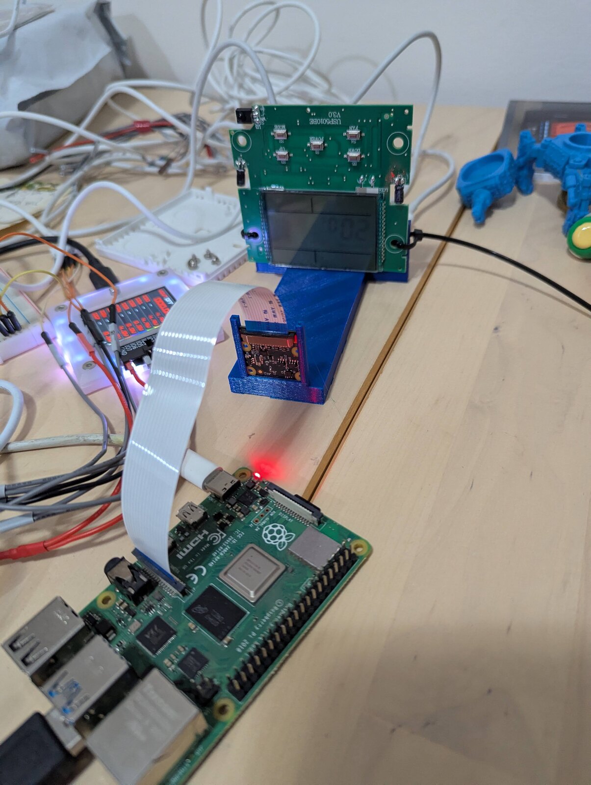
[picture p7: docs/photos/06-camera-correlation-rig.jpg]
Camera + Bus Pirate correlation rig
  
As skunkworks as I got:
1. rpi running some Linux (Debian/Arch, don't remember), connected to my wifi and SSH-accessible
2. Buspirate  
   1. connected to breadboard (cut on the left), and through it to the HVAC controller
   2. connected to the rpi via USB, operating in SUMP (transmitting relatively-raw data over USB to be read by sigrok)
3. rpicam  
   1. connected to rpi via the ribbon cable
   2. mounted on my 3d-printed camera-lcd-holder
   3. pointing at the lcd panel, so it sees the mode, compressor indicator, fan, temps
4. lcd panel  
   1. removed from the plastic case, and instead mounted on my 3d-printed holder
   2. held in place by zip-ties which were a bit fiddly, but as long as a 1-meter no-fly-zone around the table was maintained, worked.
5. breadboard  
   Allows a 3-way splitter, connecting the HVAC controller to both lcd panel and buspirate.  
   This allows me to both read the SPI data via the buspirate, and display it on the lcd panel to be captured by the camera

The code side of this was a shell/python monstrosity on the rpi that does the following:
1. Grabs photo via the rpicam of the LCD panel
2. Reads some traffic via buspirate
3. Grabs another photo via the rpicam
4. Uses some poor-mans-computer-vision Python to extract digits / modes from the panel, preferring marking things as unknown over guessing
5. Builds a "package" directory with the before,after, data capture, and a "manifest" including the interpreted data, also noting if the extracted lcd data differs before/after (making it "dirty" as we can't rely on the capture to compare LCD and wire data)

This script was used to extract a lot of packages and then employ LLM (I think Opus 4.x) to compare them and reverse engineer the wire protocol.

### Arduino R4 and Bus Pirate
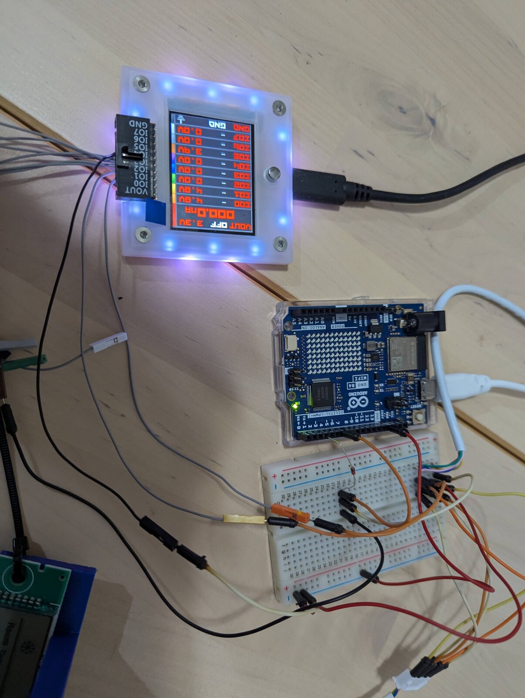
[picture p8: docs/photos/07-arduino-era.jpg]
Arduino R4 and Bus Pirate
  
This was the write-decoding part.  
The Arduino is connected in 3 wires to the rpi:
1. gnd
2. IR in (to learn IR commands from the remote)
3. IR out (to try imitating them)

The breadboard is still connected to the LCD panel and the Bus Pirate, in addition to the HVAC controller and the Arduino.
This time, I had the rpi record the before-state, IR command, after-state from the Bus Pirate, then try and send the same command from the Arduino to see if I can get the same effect.  
Once I managed that, I reverse-engineered the IR commands to try and compose new ones, sent them via the Arduino, and tested via the Bus Pirate whether they had the wanted effect

## Working prototypes

### Working Arduino setup
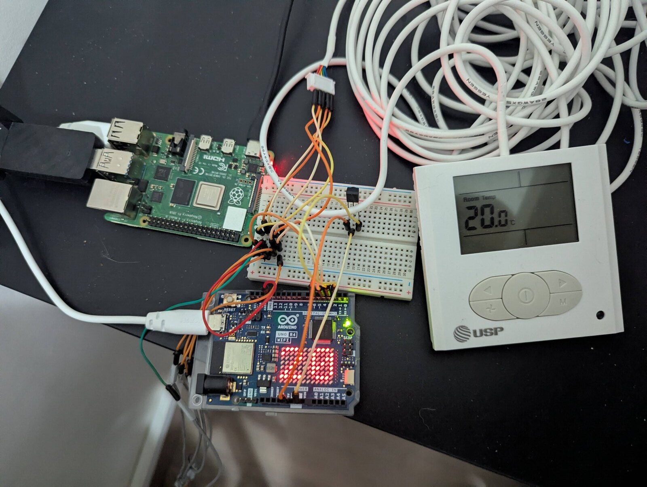
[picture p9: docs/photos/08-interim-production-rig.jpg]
Working Arduino setup
  
The Bus Pirate is now gone. The Arduino is now doing reading data and writing IR commands.  
It uses some custom code to connect to homeassistant over MQTT (mosquitto) and expose a climate-control entity, which worked.  
I used an Arduino R4 I found because it has wifi, and unlike ESP32 boards (of which I had a bunch), it's ok with 5v.  
Because it's an R4, it comes with the LED matrix which I had displaying the current temperature for fun.  
This setup worked for a couple of weeks until I gave up on maintaining the delicate cabling and moved to PCB design.

## PCBs!

### First custom boards with rework note
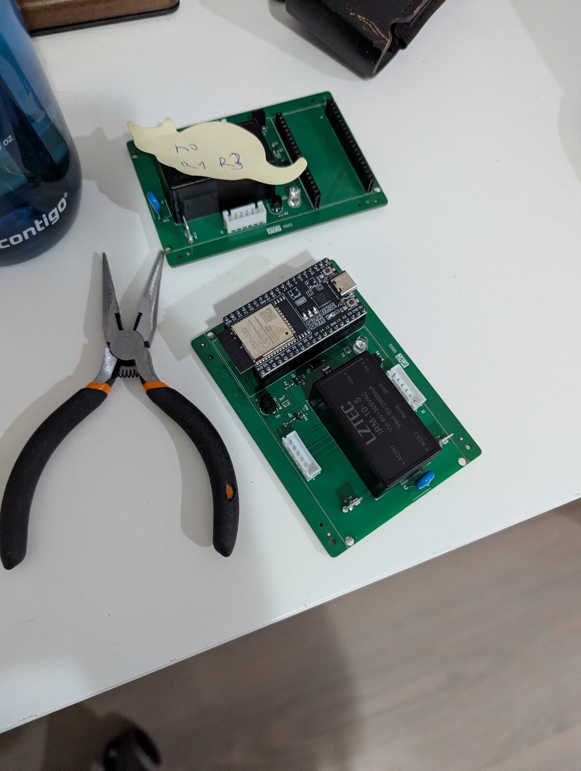
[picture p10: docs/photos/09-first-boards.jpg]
First custom boards with rework note
  
These are the v1 boards I got. They didn't work at all, and on one of them I tried solving things by breaking some components so I marked it.  
I might upload more.

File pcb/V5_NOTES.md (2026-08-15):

# v5 Backlog (if a v5 ever happens)

Accumulated from v4 arrival/bring-up. None of these justify a respin alone.

- **Silkscreen pin labels on J1/J2** (IR/GND/5V/DATA/CLK/NC) — missed in the v4
  spec; only the pinout table existed, silk marking was never required.
- **L/N markings at the screw terminal (J5)** — also missing. Electrically
  irrelevant on this board (Hi-Link AC input is polarity-insensitive, varistor
  symmetric, no AC-side fuse), but electricians expect them. For the record on
  v4: N = outer terminal (nearest left board edge), L = inner (J5 pad 1 = L at
  15.8mm from edge, pad 2 = N at 8.2mm).
- **Silk polarity marks** for C6 (+/−) — the footprint carries only a corner
  notch; assembly is CPL-driven so it built fine, but hand-rework has no guide.
- **Specify mounting hole size explicitly** — v4 vendor chose 2.1mm (v3 was
  3.2/M3); nobody specced it, discovered at case-update time. M2 hardware now.
- Consider specifying board name/version on silk ("BREEZY v4.x") near the logo.

## v5 flagship candidate: DATA-line driver for bus-injected keypresses
One open-collector transistor on DATA (like Q1 on IR) + a spare GPIO, driven
CLK-synchronously, lets breezy forge panel button presses (codes mapped
2026-08-07, see ir_commands.md). Native control path: no IR, no decode
self-poisoning, instant verification. Also: DRY mode (reply byte6=0x40)
exists and is unreachable from our IR tables - capture the remote's dry
button or reach it via forged mode presses.

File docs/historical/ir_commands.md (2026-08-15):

# IR Protocol Documentation

> **Looking for the clean spec?** This file is the chronological lab
> notebook (discoveries, retractions, splitter-era views). The current-truth
> references are `PROTOCOL_IR.md` (the IR command language) and
> `PROTOCOL_BUS.md` (the controller<->panel bus).

## THE RAW BUS DIALECT (2026-08-04..06) - read this first

Everything below this section was reverse-engineered downstream of the AC's
"splitter" - an active protocol translator (NOT passive), which engages ONLY
when its input is fed through a MIRRORED cable (the AC's special cable is
mirror-wired; fed straight it passes the raw bus through untouched). The
permanent install removes it; the raw dialect below is what breezy decodes
there. The IR protocol (this file's main subject) is unchanged.

- The raw bus runs a **33ms poll/response cycle**: 113-bit master frames
  headed `95 5F` (controller->panel, the DISPLAY commands), short ~36-bit
  polls answered after a ~611µs turnaround by **~76-bit replies headed
  `60 00`** (panel->controller).
- **Replies carry the old dialect's fields at the old offsets**: byte4 set
  temp (bit-reversed nibble + 16), byte5 fan (`80/84/88/8C`), byte6 mode
  (`20/80/C0`).
- **Reply byte2 is a BITFIELD: bit `0x08` = POWER, bit `0x02` = compressor**
  (2026-08-07, full-bus OFF/ON diff, unanimous over ~550 replies: off = `00`,
  on-idle = `08`, on-cooling = `0A`). The old "`0x0A` = compressor" reading
  was both bits at once - the only combination ever correlated. Mode/set/fan
  mirror the live store even while off; byte2 does NOT.
- **Reply byte3 bit7 flaps only while ON** (unmapped flag - fan spinning?).
  Filtering on `byte3 == 0` silently discarded a third of on-state replies;
  the slip filter now masks it and the vote skips byte3.
- **Master byte[10] was NEVER power** (retracted 2026-08-07): the same diff
  showed it pinned at `0x44` in BOTH states (flickering `44<->88` because the
  controller alternates a 112-bit master form with one fewer mid-frame bit).
  The 2026-08-06 `0x01/0x02`-off readings were a context coincidence, still
  unexplained. Masters DO carry power redundantly at byte7 bit `0x40`
  (off `00`, on `40/44`) - unused, kept as a spare witness.
- **byte7 is NOT room temp** (retracted 2026-08-06: sat at 0x00 through LCD
  room 25->24 and setpoint churn; earlier drift tracked something else,
  suspect compressor activity). The real room field is unlocated - suspect
  byte8, which also refuses to derive as a checksum. A passive collector on
  a spare host is correlating raw bytes against a second tap's oracle
  reading. (Both halves of this were later overturned: byte7's low nibble IS
  half the room field, and byte8 does derive - see PROTOCOL_BUS.md.)
- **IR acceptance SOLVED (2026-08-07): there was never an acceptance
  problem.** The HVAC beeps AND applies FIRST frames within ~1s, always
  (dual-witness proof). All historical "misses" were SELF-JAMMING: our own
  transmission poisons our own decode for ~3-11s; impatient verification
  read stale state and retried, each retry re-poisoning the decode (13-send
  storms). The remote's ~15% re-press rate is optical reception loss. Fixes:
  freshness-gated verification + direct-status comparison + backoff. Beep =
  ack = acceptance. CLOSED 2026-08-07 night: the post-TX decode-poison was
  vote starvation from since-fixed decode bugs (byte3 filter, master-vote
  power); measured post-fix, replies resume 0.52s after a full blast.
- **POWER frames are toggle-with-embedded-state** (2026-08-07, remote
  captures + 4/4 live validation): a distinct header/separator space
  (~3773µs vs ~2813) marks a power frame; its payload is
  `[mode/fan code][TEMP_BYTES[temp]][8 zeros][tail 0000011]` and a press
  TOGGLES power, waking the unit DIRECTLY into the embedded state (single
  blast, one beep - no on-then-command two-step). The remote holds no on/off
  state; "restores the pre-off snapshot" was a misread of misfiled mode
  codes (the old `POWER_TOGGLE_BYTES 0xF4` was really the heat/auto code -
  hence every "restore" landed heat). Toggle retries are PARITY-DESTRUCTIVE:
  never re-send a power frame against a power reading older than the send.
- **THE SPELLING IS THE CODE** (2026-08-07 full capture session, all 12
  mode/fan combos): heat/med and cool/med share the bit string `1111100`
  and differ ONLY in symbol spelling (`LL LM LS LM` vs `LM LS LL LM`) - the
  receiver reads symbols, not bits. Code-region spellings by family (temp/
  zeros/tail then follow the Standard state machine seeded by the code):
  | fan  | heat (`LL...`)       | fan_only (`SS LL...`)   | cool (`LM LS...`)       |
  |------|----------------------|-------------------------|-------------------------|
  | auto | LL LL SS LM SS SS    | SS LL SS SS LM SS SS    | LM LS SS SS LM SS SS    |
  | low  | LL LM SS SS SS SS SS | SS LL LM SS SS SS SS    | LM LS LM SS SS SS SS    |
  | med  | LL LM LS LM SS SS    | SS LL LL LM SS SS       | LM LS LL LM SS SS       |
  | high | LL LL LM SS SS SS    | SS LL SS LM SS SS SS    | LM LS SS LM SS SS SS    |

  All 12 verified: 9 capture-exact, 3 grammar-derived and live-fire-proven
  (2026-08-07 self-verified run, single frame each, no retries). Cool
  bit-codes = fan_only bit-codes minus the leading 0.

Decoder: `esphome/components/breezy_spi`, `dialect: raw|splitter` (one burst
recorder ISR, two grammars). Captures: 13+ labeled logs, 2026-08-04..06.

## Protocol Overview (splitter-era dialect below)

- **Encoding**: Pulse-distance modulation
- **Carrier**: None (direct digital, not modulated 38kHz)
- **Idle state**: HIGH
- **Mark (active)**: LOW
- **Header**: ~3000µs mark, ~2800µs space
- **0-bit**: ~1000µs mark, ~900µs space
- **1-bit**: ~1000µs mark, ~1900µs space (OR ~2000µs mark, ~900µs space)
- **Frame structure**: 3 identical frames per command, ~3000µs gap between frames.
  **All three are REQUIRED** - verified 2026-08-02 by replaying a captured
  command truncated to 1 and 2 frames (both rejected) against a 3-frame control
  (accepted). The repeat is not optional redundancy.
- **Trailing**: ~4000µs final gap before idle

## Timing Format

Timings are CSV of microseconds: `mark,space,mark,space,...,65535`
- Alternating mark/space starting with mark
- 65535 signals end of transmission

## Power Toggle Command

The power toggle command uses a different format (bytes: 87 07 00 7C, 175
timings). SUPERSEDED 2026-08-07: this capture was a cool/24 power-state frame
read through the splitter-era byte lens - see "POWER frames are
toggle-with-embedded-state" in the raw-dialect section at the top; the
firmware now synthesizes power frames for any mapped mode/fan/temp.

```
2945,3879,1919,1932,1986,1866,1986,906,1013,906,1013,919,1013,906,1026,906,1013,1866,1999,893,959,1932,1999,893,1013,906,946,959,1013,906,1013,906,1013,919,1013,906,1013,906,1026,906,1013,906,1026,906,1013,906,1013,906,1026,906,1013,906,1013,919,1013,906,2919,3879,1933,1919,1999,1866,1986,906,1013,906,1013,919,1013,906,1026,906,1013,1866,1999,893,946,1945,1986,893,1013,906,1013,906,1013,906,1013,906,1013,919,1013,906,1013,906,1013,919,1013,906,1013,906,1013,906,1013,919,1013,906,1013,906,1026,906,1013,906,2945,3839,1933,1919,1999,1866,1986,906,1013,906,1013,919,1013,906,1013,919,1013,1853,1999,906,946,1946,1986,893,1026,906,1013,906,1013,906,1013,919,1013,906,1026,893,1026,906,1013,906,1026,893,1026,906,1013,906,1013,919,1013,906,1013,906,1026,893,1013,906,4012,65535
```

This toggles power on/off. When AC is on, it turns off. When off, it turns on.

## Known IR States (All Verified)

| Bytes | Mode | Temp | Fan | Source | Gen |
|---|---|---|-----|---|-----|
| 0C 06 00 60 | cool | 23°C | low | state.txt | ✓ |
| 14 06 00 60 | cool | 23°C | low | state.txt | |
| 24 06 00 60 | cool | 23°C | high | state.txt | |
| 1E 05 00 B0 | cool | 23°C | high | state.txt | |
| 1C 05 00 30 | cool | 25°C | med | state.txt | |
| 0C 16 00 30 | cool | 26°C | low | SPI status | |
| 0C 0A 00 60 | cool | 27°C | low | tested ✓ | ✓ |
| 1C 07 00 98 | cool | 27°C | med | state.txt | |
| 0C 1A 00 30 | cool | 28°C | low | tested ✓ | |
| 1C 0D 00 98 | cool | 28°C | med | tested ✓ | |
| 1C 09 00 30 | cool | 30°C | med | state.txt | |
| 06 1E 00 B0 | heat | 24°C | auto | state.txt | |
| 0E 0F 00 D8 | heat | 24°C | med | state.txt | |
| 1E 0F 00 D8 | heat | 24°C | med | tested ✓ | ✓ |
| 16 0F 00 D8 | heat | 24°C | high | state.txt | ✓ |
| 1E 03 00 B0 | heat | 25°C | med | state.txt | |
| 1E 07 00 D8 | heat | 27°C | med | state.txt | |
| 1E 0D 00 D8 | heat | 28°C | med | tested ✓ | ✓ |
| 0E 18 00 30 | heat | 16°C | high | 2026-01-01 ✓ | |
| 0E 0B 00 18 | heat | 26°C | high | 2026-01-01 ✓ | |
| 0E 11 00 30 | heat | 30°C | high | 2026-01-01 ✓ | |

**Gen column**: ✓ = can be sent via bytes using v9 algorithm (POST /remote)

## All IR Packets (Decoded but not all tested)

| Packet | Bytes (hex) | First 32 bits |
|---|---|---|
| 1766863462 | 1E 0D 00 D8 | 01111000101100000000000000011011 |
| 1766863556 | 1E 0F 00 D8 | 01111000111100000000000000011011 |
| 1766863621 | 1C 05 00 30 | 00111000101000000000000000001100 |
| 1766863642 | 1C 09 00 30 | 00111000100100000000000000001100 |
| 1766863649 | 1C 0D 00 98 | 00111000101100000000000000011001 |
| 1766863669 | 1C 07 00 98 | 00111000111000000000000000011001 |
| 1766863695 | 24 06 00 60 | 00100100011000000000000000000110 |
| 1766863703 | 0C 06 00 60 | 00110000011000000000000000000110 |
| 1766863732 | 14 06 00 60 | 00101000011000000000000000000110 |
| 1766863744 | 1E 05 00 B0 | 01111000101000000000000000001101 |
| 1766863757 | 1E 07 00 D8 | 01111000111000000000000000011011 |
| 1766863799 | 1E 03 00 B0 | 01111000110000000000000000001101 |
| 1766863807 | 1E 0F 00 D8 | 01111000111100000000000000011011 |
| 1766865563 | 16 0F 00 D8 | 01101000111100000000000000011011 |
| 1766865570 | 06 1E 00 B0 | 01100000011110000000000000001101 |
| 1766865592 | 06 1E 00 B0 | 01100000011110000000000000001101 |
| 1766865599 | 1E 0F 00 D8 | 01111000111100000000000000011011 |
| 1766865605 | 0E 0F 00 D8 | 01110000111100000000000000011011 |
| 1766865612 | 16 0F 00 D8 | 01101000111100000000000000011011 |
| 1767106461 | 87 07 00 7C | 11100001111000000000000000111110 |
| 1767110231 | 0C 0A 00 60 | 00110000010100000000000000000110 |
| 1767110740 | 0C 16 00 30 | 00110000011010000000000000001100 |
| 1767110841 | 0C 0A 00 60 | 00110000010100000000000000000110 |
| 1767111194 | 0C 1A 00 30 | 00110000010110000000000000001100 |

## Protocol Analysis

### Byte 3 - Mode Indicator
Byte 3 primarily determines the operating mode:

| Byte 3 | Mode |
|---|---|
| 0x30 | cool (only) |
| 0x60 | cool (only) |
| 0x98 | cool (only) |
| 0xB0 | cool OR heat (ambiguous) |
| 0xD8 | heat (only) |

When byte 3 = 0xB0, mode is determined by byte 0.

### Byte 0 - Fan Speed
Fan encoding differs by mode:

**Cool mode:**
| Byte 0 | Fan |
|---|-----|
| 0x0C, 0x14 | low |
| 0x1C | med |
| 0x1E, 0x24 | high |

**Heat mode:**
| Byte 0 | Fan |
|---|-----|
| 0x06 | auto |
| 0x0E, 0x1E | med |
| 0x16 | high |

### Symbol-level encoding (captured 2026-08-02 via the v4 board's RX tap)

Cool mode, fan auto (byte0 = `SS SS LS SS SS LM SS SS`), captured from the real
remote and correlated against the SPI decode for ground truth:

| Temp | byte1 symbols | symbols/frame |
|---|---|---|
| 21°C | `SS LS LM SS SS SS SS SS`... (byte1 0x28) | 31 |
| 22°C | byte1 0x24 | 31 |
| 23°C | `SS LS LM SS SS SS SS SS` (0x60) | 31 |
| **24°C** | **`SS LS LM LS LM SS SS SS`** | **30** |
| **25°C** | **`SS LS LL LM SS SS SS SS`** | **30** |

**This is why 24°C and 25°C collide in the byte tables.** They are NOT
distinguished by their byte value - they are distinguished by which *symbols*
encode the run of 1s. 25°C compresses the run using the `LL` symbol; 24°C spells
it out as `LS LM LS LM` and never uses `LL`. Anything that reasons only about
byte values will conflate them. 24°C also uses a 30-symbol frame (6 trailing
bits rather than 7), which is what `generate_24c_frame_()` in `breezy_climate`
exists to produce.

Verified working end-to-end: commanding 24°C through the climate entity lands on
24°C, and 25°C still lands on 25°C.

### Fan-only mode has a DIFFERENT frame alignment (captured 2026-08-03)

Captured from the real remote in **fan_only mode, fan medium**, correlated
against the display. byte0 was constant throughout:
`LS LL LL LM SS SS SS LS`.

| Temp | byte1 symbols | symbols/frame |
|---|---|---|
| 23°C | `LM SS SS SS SS SS SS SS` | 29 |
| **24°C** | **`LM LS LM SS SS SS SS SS`** | **28** |
| 25°C | `LL LM SS SS SS SS SS SS` | 28 |
| 26°C | `LL SS LM SS SS SS SS SS` | 28 |

**Fan-only frames are 28-29 symbols; cool is 30-31 and heat 29-30.** Fan-only's
byte0 carries two `LL` symbols, which shifts the bit alignment relative to the
other modes, so the byte1 slice above is not directly comparable to the cool
table below.

**Resolved 2026-08-04.** The 24°C frame structure is the same in every mode:
mode-normal byte0, then byte1 0x78 spelled no-LL (`SS LS LM LS LM SS SS SS`),
byte2 zeros, 6-bit tail (`SS SS SS SS LS LM`). The fan-only no-op was caused by
`generate_24c_frame_()` hardcoding **Standard** encoding for byte0: for cool's
0x24 Standard coincides with LsStart, but it spells fan-only's 0xFC as
`LL LL LL` where the remote sends `LS LL LL LM` - and the HVAC pattern-matches
the waveform, so the wrong byte0 *spelling* invalidates the whole frame. Fix:
byte0 now uses the mode's normal encoding. Validated by (a) offline
symbol-exact reproduction of all captured frames, (b) synthesizing the frame
over `send_ir_raw` and watching the SPI decode accept it, (c) 6/6 on the
fan_only/cool x 22/24/25 matrix through the climate entity.

Two failed hypotheses worth recording so nobody retries them:
- **Bits-only model**: treating LL as two 1-bits, 24°C differs from 25°C only
  by total length (30 vs 31 bits). True as arithmetic, but sending those 30
  bits with LL spelling is rejected outright - the receiver reads symbols
  (waveform), not decoded bits.
- **Cool-shaped hybrid frame in fan-only**: right byte1 spelling, wrong byte0
  spelling - also rejected. Both features must be right; a frame is accepted
  whole or not at all.

### Byte 1 - Temperature
Temperature encoding is complex - same value can represent different temps:

**Cool mode:**
| Byte 1 | Temp |
|---|---|
| 0x05, 0x06 | 23°C |
| 0x05 | 25°C |
| 0x16 | 26°C |
| 0x07, 0x0A | 27°C |
| 0x0D, 0x1A | 28°C |
| 0x09 | 30°C |

**Heat mode:**
| Byte 1 | Temp |
|---|---|
| 0x0F, 0x1E | 24°C |
| 0x03 | 25°C |
| 0x07 | 27°C |
| 0x0D | 28°C |

### Byte 2
Always 0x00 in all captured packets.

## Raw Timings for Verified States

### Cool 27°C Low Fan (1767110841)
```
3040,2813,1026,906,1026,893,1026,1866,2000,893,1026,893,1026,906,1026,893,1026,906,1013,906,1026,1866,1026,893,2000,893,1026,893,1026,906,1026,893,1026,906,1026,893,1026,906,1026,893,1026,906,1026,893,1026,906,1013,906,1026,893,1026,906,1026,893,1026,906,1013,906,1026,893,1026,1866,2000,906,2986,2826,1026,906,1013,906,1026,1866,1986,893,1026,906,1013,906,1013,906,1026,906,946,973,1026,1853,960,973,1920,960,1026,906,946,973,946,986,946,973,1013,920,946,973,946,986,946,973,946,973,946,986,946,973,946,986,946,973,946,986,946,973,946,973,960,973,946,1933,1920,986,2920,2906,946,973,946,986,946,1933,1920,973,946,986,946,973,946,986,946,973,946,973,946,1946,946,973,1920,973,946,986,946,973,946,973,946,986,946,973,946,986,946,973,946,973,960,973,946,973,946,986,946,973,946,986,946,973,946,973,946,986,946,973,946,1946,1920,973,3946,65535
```

### Cool 28°C Low Fan (1767111194)
```
3040,2813,1040,893,1040,893,1026,1853,2000,893,1026,906,1080,840,1040,880,1080,853,1066,853,1040,1853,1040,880,2013,1840,2013,880,1040,893,1026,893,1040,893,1026,893,1040,893,1026,893,1040,893,1026,893,1040,893,1026,893,1040,893,1026,893,1040,893,1026,893,1040,880,1040,1853,2000,906,3026,2800,1026,893,1040,893,1026,1853,2013,880,1040,893,1026,893,1040,893,1026,893,1026,906,1026,1853,1040,893,2000,1840,2013,880,1040,893,1000,920,1040,893,1000,920,1026,893,1040,892,1026,892,1040,893,1026,893,1013,920,1026,893,1040,880,1040,893,1026,893,1013,920,1026,1866,1973,920,2973,2853,1013,920,1026,893,1013,1880,1973,906,1013,920,1000,920,1026,906,1000,920,1040,893,1026,1853,1013,920,1973,1866,2013,880,1013,920,1026,893,1013,920,1000,920,1013,906,1040,893,1000,920,1013,920,1026,893,1013,920,1000,920,1013,920,1000,920,1000,920,1013,920,1000,1880,1986,920,4000,65535
```

### Heat 28°C Med Fan (1766863462)
```
3026,2840,1026,893,1026,1866,1986,906,1013,1866,2000,893,1026,893,1026,906,1026,893,1026,1866,1026,893,2000,1853,2000,893,1026,893,1026,906,1026,893,1026,906,1013,906,1026,906,1013,906,1026,906,1013,906,1026,906,1013,906,1040,880,1026,906,1026,893,1026,906,1013,1866,2000,906,2986,2840,1013,906,1026,1866,1986,893,1026,1866,2000,893,1013,906,1026,906,1013,906,1026,1866,1013,906,2000,1853,2000,893,1013,906,1026,893,1026,906,1026,893,1040,893,1026,893,1026,906,1013,906,1026,906,1013,906,1026,893,1026,906,1026,893,1026,906,1013,906,1026,1853,2000,906,2986,2840,1013,906,1026,1853,2000,893,1026,1866,1986,893,1026,906,1013,906,1026,893,1026,1866,1013,906,1986,1866,1986,893,1026,906,1013,906,1026,893,1026,906,1013,906,1026,906,1013,906,1026,893,1026,906,1013,906,1013,920,1013,906,946,973,1026,906,946,973,946,1933,1920,986,4013,65535
```

### Cool 25°C Med Fan (1766863621)
```
2973,2880,973,986,946,946,973,1906,1946,1906,1946,933,986,946,973,946,986,946,973,1906,986,946,1946,933,973,946,986,946,973,946,973,960,973,946,973,946,973,946,986,946,973,946,986,946,973,946,973,946,986,946,973,946,973,960,973,946,973,986,933,1906,1960,946,2946,2880,973,946,973,986,933,1906,1960,1893,1946,946,973,946,986,946,973,946,973,1906,986,946,1946,933,986,946,973,946,973,960,973,986,933,946,973,946,986,946,973,946,973,946,986,933,986,946,973,946,973,946,973,946,986,946,973,946,973,946,986,1906,1960,933,2946,2880,973,946,973,946,986,1906,1946,1893,1960,933,973,946,986,946,973,946,973,1906,986,946,1946,933,973,946,986,946,973,946,973,946,986,946,973,946,973,946,986,946,973,946,973,946,973,959,973,946,973,946,973,946,986,946,973,946,973,960,973,1906,1946,946,3986,65535
```

### Heat 24°C High Fan (1766865563)
```
2973,2880,986,946,973,1906,1946,1906,973,1000,1906,933,986,946,973,946,973,946,986,1906,1946,933,986,1906,1960,920,986,986,933,946,973,946,973,946,973,960,973,946,973,986,946,946,973,946,986,946,973,946,986,946,973,946,973,946,986,946,973,1906,1960,946,2946,2880,973,946,986,1906,1946,1893,986,946,1946,946,960,960,973,946,986,946,973,1906,1946,946,973,1906,1960,933,973,960,973,946,973,946,986,946,973,946,986,946,973,946,973,946,986,946,973,946,973,960,973,946,973,946,986,946,973,946,973,1920,1946,946,2946,2866,986,946,973,1906,1946,1906,973,946,1946,946,973,946,986,946,973,946,973,1906,1946,946,973,1906,1960,933,973,946,986,946,973,946,973,946,986,946,973,946,986,946,973,946,973,946,986,946,973,946,973,946,986,946,973,946,973,946,986,1906,1946,946,3986,65535
```

## Byte-Based Generation (v9 Algorithm)

Commands can be generated from 4 bytes using the v9 algorithm. This is implemented in:
- `test_gen.py` (Python, for testing)
- `breezy.ino` (Arduino, `generateIRTimings()`)

### Sending via Breezy HTTP API

```bash
# Send by bytes (uses v9 generation)
curl -X POST "http://breezy/remote?b0=1E&b1=0D&b2=00&b3=D8"

# Send raw timings (bypasses generation)
curl -X POST http://breezy/remote/raw -d "3026,2840,1026,893,..."
```

### Protocol Details

**Byte 3 determines frame structure:**
| Byte 3 | Mode | Bits/Frame | LL Encoding |
|---|---|---|---|
| 0xD8 | heat | 29 | isolated-1-0-1 pattern |
| 0x60 | cool | 31 | middle of 3+ consecutive 1s |
| 0x30 | cool | 30 | middle of 3+ consecutive 1s |
| 0x98 | cool | 30 | middle of 3+ consecutive 1s |

**Encoding types:**
- SS: 1026µs mark, 893µs space (0-bit)
- LS: 1026µs mark, 1866µs space (1-bit, first in alternation)
- LM: 2000µs mark, 893µs space (1-bit, second in alternation)
- LL: 2000µs mark, 1853µs space (1-bit, special pattern)

**Working commands (byte3=0xD8 heat, byte3=0x60 cool):**
- Heat mode: All 0xD8 commands work
- Cool mode: Only 0x60 commands verified working
- 0x30/0x98 commands: Encoding matches captures but don't work (unknown reason)

## Sending Commands

### Python Example (on RPi)

```python
import serial
import time

# Example: Cool 27°C Low Fan
TIMINGS_27C_COOL_LOW = "3040,2813,1026,906,..."  # Full timing string

ser = serial.Serial("/dev/ttyACM2", 115200, timeout=2)
time.sleep(2)  # Wait for Arduino reset
ser.readline()  # Discard ready message

# Switch to direct mode (REQUIRED)
ser.write(b"d\n")
time.sleep(0.2)
ser.readline()

# Send command
ser.write((TIMINGS_27C_COOL_LOW + "\n").encode())
time.sleep(1.5)
print(ser.readline().decode().strip())  # "Sent N timings"

ser.close()
```

## Capturing New Commands

Use `ir_capture.sh` on RPi:

```bash
~/packet_capture/ir_capture.sh
```

This will:
1. Read AC status via SPI (before)
2. Capture IR + SPI for ~1.75s
3. Read AC status via SPI (after)
4. Fail if no valid SPI frames or no IR activity

Extract timings from capture:

```bash
sigrok-cli -i recording.sr -C 5 -O csv | python3 decode_ir.py
```

## Panel button codes on the raw bus (mapped 2026-08-07, unit off)

Buttons appear in TWO layers simultaneously:

1. The 36-bit polls swap their idle signature `95 5F FF F1 5x` for a
   per-button code nibble (echoed in the next byte, check-ish byte after):
   power=`95 50 F0 F5`, temp_up=`95 52 F2 F4`, mode=`95 54 F4 F7`,
   fan=`95 58 F8 F3`, temp_down=`95 5C FC F0`.
2. The 60 00 replies flag the press class in byte2 (+= 0x01 temp, 0x04 mode,
   0x0C power) with byte3 bit7 set - the forgery target for bus-injected
   keypresses (v5: needs a DATA-line driver transistor; v4 taps are
   read-only by design).

BONUS: mode cycling exposed reply byte6 = 0x40 - per the user this is the
WATERDROP icon = DRY/dehumidify. **CONFIRMED 2026-08-14, with a caveat**:
most archived `0x40` frames are shifted HEAT frames (`0x20<<1 = 0x40`, a
VERBOSE-logging capture defect), but 62 checksum-authenticated frames from
this very session are genuine, and 61 of them carry fan=low - which matches
the remote refusing any other fan speed in DRY. So `0x40` = DRY holds, and
AUTO = `0x00` (live-probed). See PROTOCOL_BUS.md. The panel also has a triangle-of-arrows
icon = AUTO mode (byte6 code unobserved). Both exist on the unit and are
DELIBERATELY UNSUPPORTED (user: "I don't find them interesting"); the
decoder reports mode "unknown" if the panel is ever put there. Our IR
tables cover heat/cool/fan_only only.

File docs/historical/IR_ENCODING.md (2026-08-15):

# IR Encoding Protocol Documentation

## Overview

This document describes the IR encoding protocol for the AC unit, reverse-engineered from captured IR signals.

## Bit Encoding

The protocol uses 4 symbols to encode bits:

| Symbol | Mark (µs) | Space (µs) | Bits Encoded |
|---|---|---|---|
| SS | ~1000 | ~920 | 0 |
| LS | ~1000 | ~1880 | 1 |
| LM | ~1966 | ~920 | 1 |
| LL | ~1966 | ~1875 | 11 |

## State Machine

The choice of symbol depends on the current state and the upcoming bits. There are 5 states:

- `fresh` - Initial state before any bits
- `after_0` - After zeros from `after_LL` or `after_LS`
- `after_LL` - After encoding LL
- `after_LM` - After encoding LM
- `after_LS` - After encoding LS

### State Transitions for Zero Bits

| Current State | On Zero | Next State |
|---|---|---|
| fresh | SS | after_LM |
| after_0 | SS | after_0 |
| after_LL | SS | after_0 |
| after_LM | SS | after_LM |
| after_LS | SS | after_0 |

### State Transitions for One Bits

| Current State | Next Bit | Symbol | Next State |
|---|---|---|---|
| fresh | 1 | LL | after_LL |
| fresh | 0 | LS | after_LS |
| after_0 | 1 | LL | after_LL |
| after_0 | 0 | LM | after_LM |
| after_LL | (any) | LM | after_LM |
| after_LM | (any) | LS | after_LS |
| after_LS | 1 | LL | after_LL |
| after_LS | 0 | LM | after_LM |

Key insight: `after_0` uses LM for a single 1, while `fresh` uses LS. This distinction is critical.

### Alternative Encoding (No-LL)

Some temperature settings (notably 24°C) use a simpler encoding without LL symbols:

- **0** → SS, reset to use LS for next 1
- **1** → alternates between LS and LM, starting with LS after a 0

This produces longer signals (more symbols for the same bits) but avoids the complexity of the LL lookahead.

## Frame Structure

### Power Toggle Command

- **Header**: 3000µs mark, 3806µs space
- **Separator**: 2953µs mark, 3810µs space
- **Trail**: 3980µs
- **3 identical frames**
- **30 bits per frame** (24 data bits + 6 extra bits)

Bytes:
- byte0: 0xf8 (fixed)
- byte1: temperature (bit-reversed encoding, see below)
- byte2: 0x00
- byte3: 0x03 (lower 6 bits = 000011)

### Heat Mode Command

- **Header**: 2994µs mark, 2846µs space
- **Separator**: 2953µs mark, 2856µs space
- **Trail**: 3976µs
- **3 IDENTICAL frames** (all frames are the same)
- **31 bits per frame** (24 data bits + 7 extra bits)

Bytes:
- byte0: 0x74 (fixed for heat mode)
- byte1: temperature encoding (see table below)
- byte2: 0x00
- byte3: 0x03 (lower 7 bits = 0000011)

## Temperature Encoding

### Heat Mode Temperature Bytes

These are the actual byte1 values decoded from captured heat mode commands:

| Temp | byte1 (hex) | Notes |
|---|---|---|
| 16°C | 0x0c | |
| 17°C | 0x18 | |
| 18°C | 0x14 | |
| 19°C | 0x30 | |
| 20°C | 0x3c | |
| 21°C | 0x28 | |
| 22°C | 0x24 | |
| 23°C | 0x60 | |
| 24°C | 0x78 | *hybrid encoding (see below)* |
| 25°C | 0x78 | *same byte1 as 24°C, different encoding* |
| 26°C | 0x74 | |
| 27°C | 0x50 | |
| 28°C | 0x5c | |
| 29°C | 0x48 | |
| 30°C | 0x44 | |

### Special Case: 24°C

24°C uses a hybrid encoding scheme:
- **byte1**: 0x78 (same as 25°C!)
- **6 extra bits** (30 bits per frame instead of 31)
- **Fan speed byte0**: Uses standard fan bytes (auto=0x74, low=0x60, med=0x5c, high=0x78)
- **Key difference**: Uses LS-LM alternation (no LL) for byte1's `1111` sequence instead of `LS LL LM`

The distinction between 24°C and 25°C is subtle:
- 24°C: byte1=0x78 encoded with no-LL for the 1111 nibble, 30 bits total
- 25°C: byte1=0x78 encoded with standard LL encoding, 31 bits total

Symbol sequences for byte1's `01111000`:
- 24°C: `SS LS LM LS LM SS SS SS` (8 symbols for 8 bits)
- 25°C: `SS LS LL LM SS SS SS` (7 symbols for 8 bits via LL encoding)

### Power Toggle Temperature Encoding

Power toggle uses **bit-reversed** versions of the heat mode bytes:

| Temp | Heat byte | Power byte (reversed) |
|---|---|---|
| 16°C | 0x0c | 0x30 |
| 17°C | 0x18 | 0x18 |
| 18°C | 0x14 | 0x28 |
| 19°C | 0x30 | 0x0c |
| 20°C | 0x3c | 0x3c |
| 21°C | 0x28 | 0x14 |
| 22°C | 0x24 | 0x24 |
| 23°C | 0x60 | 0x06 |
| 24°C | 0x78 | 0x1e |
| 25°C | 0x78 | 0x1e |
| 26°C | 0x74 | 0x2e |
| 27°C | 0x50 | 0x0a |
| 28°C | 0x5c | 0x3a |
| 29°C | 0x48 | 0x12 |
| 30°C | 0x44 | 0x22 |

## Bit Order

All bytes are transmitted **MSB-first** (most significant bit first).

## Implementation

See `ir_encoder.py` for a complete Python implementation:

```python
from ir_encoder import generate_power_toggle, generate_heat, send_raw_timings

# Power toggle at 21°C
timings = generate_power_toggle(temp=21)
send_raw_timings(timings)

# Heat mode at 21°C with auto fan
timings = generate_heat(21, fan='auto')
send_raw_timings(timings)

# Heat mode at 24°C (only med/high fan available)
timings = generate_heat(24, fan='med')
send_raw_timings(timings)
```

## Files

- `ir_encoder.py` - Main encoder with `generate_power_toggle()`, `generate_heat()`, and low-level command functions
- `test_encoder.py` - Test harness with encoding comparisons
- `decode_timings.py` - Analysis tool for captured IR data

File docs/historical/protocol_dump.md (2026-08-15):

# AC LCD Protocol Reverse Engineering - Data Dump

## Hardware Setup

- **Bus Pirate 5** connected via:
  - `/dev/ttyACM0` - Interactive terminal (picocom, INFRARED mode, etc.)
  - `/dev/ttyACM1` - OLS/SUMP mode for logic capture (sigrok-cli)
- **Target**: AC controller LCD panel (USP5010BE) connected to hub board (USP5020)
- **Capture tool**: `sigrok-cli` with OLS driver

### Wiring (Bus Pirate → AC)
| Bus Pirate | Signal | Function |
|---|---|---|
| IO0 | Data | Bidirectional SPI data (TDM: controller sends display, panel sends buttons) |
| IO1 | Clock | ~7.1kHz clock (controller generates) |
| IO2 | ??? | Purpose unknown - stays high, brief low at end of captures |
| IO4 | IR TX | For IR injection via diode (IRTX in INFRARED mode) |
| IO5 | IR RX | Raw demodulated IR signal from receiver (monitoring) |
| GND | GND | Ground |
| +5V | VCC | Power (not captured) |

**Wire summary (active signals):**
- **Data (IO0)**: Single bidirectional data line, time-division multiplexed
- **Clock (IO1)**: SPI clock from controller, ~7.1kHz, asymmetric duty cycle
- **IR RX (IO5)**: Panel's IR receiver output, raw demodulated signal to controller
- **IR TX (IO4)**: BP5 IRTX output → diode → IR line (for injection)

## Protocol Characteristics

- **NOT I2C** (despite initial assumption) - proven by analyzing START/STOP conditions
- **SPI-like** clocked serial protocol
- Clock on CH1, Data on CH0
- Data sampled on clock rising edge
- Mode: CPOL=0, CPHA=1 works for decoding

### Clock Timing (Critical for Capture)
- **Clock frequency**: ~7.1 kHz (period ~140µs)
- **Duty cycle**: Highly asymmetric (~80% low, ~20% high)
- **High pulse width**: ~25-30µs (very short!)
- **Minimum sample rate**: 75kHz required for reliable capture
  - At 75kHz: 2-3 samples during high pulse → reliable edge detection
  - At 50kHz: only 1 sample during high pulse → unreliable, causes decode errors
  - Below 50kHz: often misses high pulse entirely → garbage data
- **Buffer limit**: Bus Pirate OLS mode holds 131072 samples max
- **Max capture duration**: 131072 / 75000 = **1.75 seconds** at 75kHz

### Frame Structure
- **112 bits (14 bytes) per frame**
- **~6 Hz refresh rate** (~170ms between frames)
- Frames repeat identically when display is stable
- Partial frames at capture boundaries are normal (ignore minority patterns)

## Packet Format (14 bytes)

```
Byte:  0  1  2  3  4  5  6  7  8  9  10 11 12 13
       XX 00 XX XX XX XX 20 XX XX XX XX FF FF XX
       └──────────── Controller ──────────────┘
                                       └─Panel─┘
```

**Bidirectional protocol on single data line (time-division multiplexed):**
- Bytes 0-10, 13: Controller → Panel (display state)
- Bytes 11-12: Panel → Controller (button input)
- Data line is likely open-drain with pull-up (idle = `FF FF` = all 1s)
- Panel gets 2-byte window per frame (~6Hz) for button codes

### Constant Bytes
| Byte | Value | Notes |
|---|---|---|
| 1 | 0x00 | Always zero |
| 11 | 0xFF | Always 0xFF (panel→controller, idle) |
| 12 | 0xFF | Always 0xFF (panel→controller, idle) |

### Confirmed Mappings (HIGH CONFIDENCE)

**Byte 2 - Power & Compressor:**
| Value | Meaning |
|---|---|
| 0x00 | AC off |
| 0x08 | AC on, compressor off |
| 0x0A | AC on, compressor on (heating) |

**Byte 4 - Set Temperature (16-30°C):**

Encoding: `byte4 = bit_reverse_4bit(temp - 16)`

| Temp | Offset | Binary | Reversed | Hex |
|---|---|---|---|-----|
| 16°C | 0 | 0000 | 0000 | 0x00 |
| 20°C | 4 | 0100 | 0010 | 0x02 |
| 24°C | 8 | 1000 | 0001 | 0x01 |
| 25°C | 9 | 1001 | 1001 | 0x09 |
| 30°C | 14 | 1110 | 0111 | 0x07 |

**Byte 5 - Fan Speed:**
| Value | Fan |
|---|-----|
| 0x80 | auto |
| 0x84 | medium |
| 0x88 | high |
| 0x8C | low |

**Byte 6 - Mode:**
| Value | Mode |
|---|---|
| 0x20 | heat |
| 0x80 | cool |
| 0xC0 | fan-only |

**Panel button press (bytes 11-12):**
| State | Bytes 11-12 |
|---|---|
| Idle | 0xFF 0xFF |
| Button pressed | 0x87 0x0F |

### Unconfirmed / Unknown

| Byte | Observations |
|---|---|
| 0 | Frame type? (0x60/0xE0 varies) |
| 3 | Unknown (0x00/0x80) |
| 7 | Room temperature integer (see encoding below) |
| 8 | Room temperature decimal / display state? (varies) |
| 9 | Display state? (0x99/0x59/0xD9) |
| 10 | Variable - display mux? |
| 13 | Variable - checksum? |

**Byte 7 - Room Temperature Encoding (CONFIRMED):**

Uses 2-bit reversed encoding with range flag in bits[1:0]:

| bits[1:0] | Range | Formula |
|---|---|---|
| 0x3 (11) | 20-23°C | `20 + bit_reverse_2bit(byte7 >> 2)` |
| 0x0 (00) | 24-27°C | `24 + bit_reverse_2bit(byte7 >> 2)` |

Verified mappings:
| Room Temp | Byte 7 | Binary |
|---|---|---|
| 20°C | 0x03 | 0000 0011 |
| 21°C | 0x0B | 0000 1011 |
| 22°C | 0x07 | 0000 0111 |
| 23°C | 0x0F | 0000 1111 |
| 24°C | 0x00 | 0000 0000 |
| 25°C | 0x08 | 0000 1000 |
| 26°C | 0x04 | 0000 0100 |
| 27°C | 0x0C | 0000 1100 |

Note: Byte 8 varies even for same room temp - may encode decimal part or display multiplex state.

**IR remote vs panel buttons:**
- Panel button press: `87 0F` code visible in SPI bytes 11-12
- IR remote press: raw IR signal on CH5 (IO5), not in SPI frames

## IR Protocol (CH5 / IO5)

The IR receiver on the panel outputs raw demodulated signal on IO5. Controller decodes directly.

### IR Signal Characteristics
- **Modulation**: Pulse-distance encoding
- **Leader**: ~3ms LOW + ~3ms HIGH
- **Bit encoding**:
  - Mark: ~1ms LOW (constant)
  - Space: ~950µs HIGH = bit 0, ~1900µs HIGH = bit 1
- **Frame**: 24 bits, repeated 3x with ~3ms gaps

### Known IR Commands

| IR Code | Observed Result |
|---|---|
| 63 00 01 | heat mode, temp commands |
| 62 00 00 | heat mode, temp up? |
| 62 00 01 | heat mode, temp down? |
| 22 00 00 | cool mode, temp up? |
| 22 00 01 | cool mode, temp down? |
| 43 00 01 | fan speed (heat) - encoding unclear |
| 40 C0 00 | fan speed (heat) - encoding unclear |

### Byte 1 Pattern (partial)
- High nibble `6` = heat mode
- High nibble `4` = heat mode (fan?)
- High nibble `2` = cool mode
- Low nibble `2` = temp down?
- Low nibble `3` = temp up?
- Low nibble `0` = fan?

### Open Issues
- **Fan encoding unclear**: Same IR code `43 00 01` observed for different fan state transitions (med→high AND high→auto). Remote displays current fan state, suggesting full state encoding, but codes don't match.
- **75kHz sample rate may be insufficient** for accurate IR decoding
- Need more systematic captures to decode full protocol

### IR Capture TODO
See `ir_capture_todo.md` for remaining captures needed.

### IR Injection (Sending Commands)

**Problem:** Directly connecting to the IR line loads it down and blocks the real IR receiver. The panel's IR receiver output is too weak to drive additional loads.

**Solution:** Use a diode to allow injection without interference:

```
IR Line ───┬─────────────── to AC Controller
           │
           ├─── IO5 (direct - monitoring)
           │
           └──►|──── IO4 (IRTX output)
           anode  cathode (stripe on diode)
```

**How it works:**
- When IO4 goes LOW (transmitting mark): diode forward-biased, pulls IR line LOW ✓
- When IO4 is HIGH (idle/space): diode reverse-biased, IO4 disconnected, no interference ✓
- Real IR receiver continues working normally ✓

**Components needed:**
- 1N4148 signal diode (or similar: 1N914, etc.)

**BP5 INFRARED mode for injection:**
```bash
# Enter INFRARED mode: m → 11 → y
# Send IR command (aIR format):
irtx $0:3000,3000,1000,950,1000,1900,...,1000,65535,;
#     └─freq  └─leader  └─bit marks/spaces      └─end
```

**aIR format:** `$<freq_khz>:<mark1>,<space1>,<mark2>,<space2>,...;`
- Use `$0` for no modulation (injecting to demodulated line)
- Use `$38` for 38kHz modulation (if using IR LED)
- Times in microseconds

## Recorded Samples

All recordings in `~/bla/recordings/` with naming: `room{X}_mode-{Y}_set{Z}_fan-{W}_comp-{V}_{timestamp}.sr`

### Captured Data

| Room | Mode | Set | Fan | Comp | Bytes (hex) |
|---|---|-----|-----|---|---|
| 20 | heat | 25 | high | off | 60 00 08 80 09 88 20 03 CE 59 55 FF FF 15 |
| 20 | heat | 25 | low | off | 60 00 08 80 09 8C 20 03 C9 59 55 FF FF 15 |
| 20 | heat | 25 | med | off | 60 00 08 80 09 84 20 03 C1 59 55 FF FF 15 |
| 20 | heat | 25 | med | on | E0 00 0A 00 09 84 20 03 C3 99 8A FF FF 8F |
| 20 | heat | 26 | high | off | 60 00 08 80 05 88 20 03 C1 59 55 FF FF 15 |
| 20 | heat | 26 | low | off | 60 00 08 00 05 8C 20 03 C5 99 55 FF FF 15 |
| 20 | heat | 26 | med | off | 60 00 08 80 05 84 20 03 C9 59 55 FF FF 15 |

## Capture Settings (IMPORTANT)

The following settings are required for clean captures:

```bash
sigrok-cli -d ols:conn=/dev/ttyACM1 \
    --config samplerate=75000 \
    --samples 37500 \
    --channels 0,1,2,5 \
    -o output.sr
```

| Setting | Value | Notes |
|---|---|---|
| Sample rate | **75kHz** | Minimum for reliable capture (see Clock Timing above) |
| Samples | 37500 | ~0.5s capture, yields 8-10 frames |
| Max samples | 131072 | OLS buffer limit → max 1.75s at 75kHz |
| Channels | 0,1,2,5 | Data, Clock, Sync, Sync |

**Note**: On RPi, user `nitz` has Bus Pirate access (dialout group).

## Decoding Commands

```bash
# Capture new sample (from local machine)
./capture_recording.sh [output.sr]

# On RPi directly (as bob)
./record_ac.sh <room_temp> <mode> <set_temp> <fan> <compressor>
./record_ac.sh 25 heat 22 high on
./record_ac.sh 25 off

# Decode .sr file to hex bytes
sigrok-cli -i FILE.sr -P spi:clk=1:mosi=0:cpol=0:cpha=1 -A spi=mosi-data

# Group into 14-byte frames
sigrok-cli -i FILE.sr -P spi:clk=1:mosi=0:cpol=0:cpha=1 -A spi=mosi-data | \
    grep -oP '[0-9A-F]{2}' | paste -d' ' - - - - - - - - - - - - - -

# View raw waveforms
sigrok-cli -i FILE.sr -O ascii
```

## Remaining Work

1. **Room temperature encoding** - Bytes 7-8, encoding unclear (values vary even for same temp - display mux?)
2. **Byte 0, 3, 9, 10, 13** - Purpose unknown

**Note:** Backlight is likely controlled locally by the panel (timer-based after button/IR press), not transmitted in the protocol.

## Open Questions

1. What do bytes 7-8 encode for room temperature?
2. Is byte 13 a checksum?
3. What is byte 0 (0x60/0xE0)?
4. What is byte 3 (0x00/0x80)?

## Standalone Operation (Future)

For WiFi-enabled standalone control without laptop/Bus Pirate:

### Hardware Options
- **Arduino UNO R4 WiFi** - 5V logic (matches panel), has ESP32-S3 for WiFi
- **ESP32 DevKit** - 3.3V logic, needs level shifter

### Components for ESP32 (3.3V) build
| Component | Purpose |
|---|---|
| 1N4148 diode | IR injection (same as BP5 setup) |
| Bidirectional level shifter | 3.3V ↔ 5V for SPI signals |
| 5V→3.3V regulator (e.g., AMS1117-3.3) | Power from panel (optional) |

### Components for Arduino R4 WiFi (5V) build
| Component | Purpose |
|---|---|
| 1N4148 diode | IR injection |
| (no level shifter needed) | R4 is 5V logic |

### Power Considerations
- Panel's 5V rail capacity is unknown
- ESP32 WiFi can spike to 300-500mA
- Safer to use separate USB power initially
- Measure panel 5V capacity before powering from it

## Files

- `rpi/read_status.sh` - Read current AC state via SPI
- `rpi/capture_packet.sh` - Periodic SPI capture
- `rpi/ir_capture.sh` - IR signal capture with photos
- `packets/` - Captured recordings

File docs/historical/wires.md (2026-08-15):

# Wire Color Mapping

## White Cable (LCD) → Red Cable (Extension)

Based on LCD panel labels (I..., GN..., +5..., DA..., CL...):

| White Cable | Red Cable | Signal |
|---|---|---|
| Blue | Red | IR |
| Turquoise | Yellow | GND |
| Yellow | Turquoise | +5V |
| Orange | Blue | DATA |
| Red | White | CLK |
| (empty) | Black | NC |

## Bus Pirate 5 Connections (SPI monitoring)

| Red Cable | BP5 Pin | Signal |
|---|---|---|
| Red | IO5 | IR RX (monitoring) |
| Yellow | GND | GND |
| Blue | IO0 | DATA |
| White | IO1 | CLK |

BP5 ports:
- `/dev/ttyACM0` - Interactive terminal (picocom)
- `/dev/ttyACM1` - OLS/SUMP mode (sigrok-cli)

## Arduino UNO R4 WiFi Connections (IR transmission)

| Arduino Pin | Connection | Target |
|---|---|---|
| ~3 (D3) | → 1N4148 cathode (stripe) → anode → | IR line (diode path - NOT WORKING) |
| ~6 (D6) | direct | IR line (Red on red cable) - WORKING |
| GND | direct | Common GND |

Arduino port: `/dev/ttyACM2`

### Working Setup: Direct Connection (Pin 6)

```
IR Line ───┬─────────────── to AC Controller
           │
           ├─── BP5 IO5 (monitoring)
           │
           └─── Arduino D6 (direct - WORKING)
```

**Critical: Pin must be INPUT (high-Z) when idle so real remote still works.**
**When transmitting: set OUTPUT, HIGH, wait 100µs, then send timings.**

The diode path (D3) did not work - possibly due to voltage drop or timing issues.

### Arduino Sketch

Located at: `rpi:~/ac_ir/ac_ir.ino` and `arduino/ac_ir.ino`

Commands via serial (115200 baud):
- `t` - Test toggle (100ms pulse)
- `b` - Blink LED 3x (visibility test)
- `d` - Switch to DIRECT mode (pin 6) - USE THIS
- `p` - Switch to DIODE mode (pin 3)
- `r` - Repeat last command continuously
- `s` - Stop repeating
- CSV timings - Send IR (e.g., `3040,2813,1026,906,...,65535`)

### Verified Working IR Commands

See `ir_commands.md` for captured and tested IR command timings.

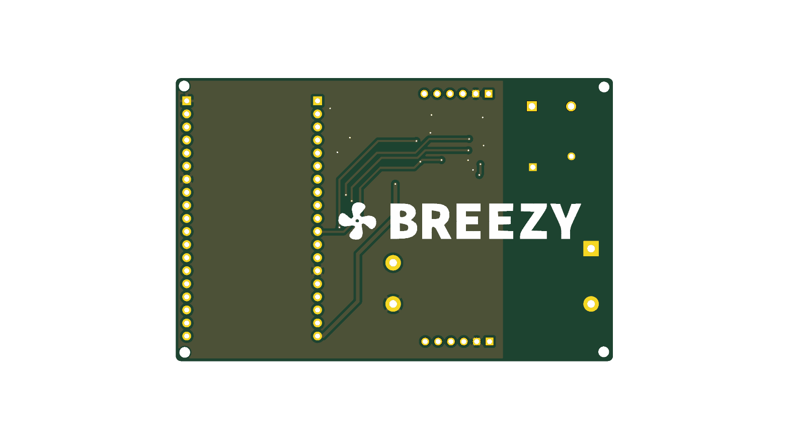
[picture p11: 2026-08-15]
pcb/breezy_v4/renders/board_back.png

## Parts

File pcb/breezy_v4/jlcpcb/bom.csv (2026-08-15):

Designator | Footprint | Quantity | Value | LCSC Part #
C1, C4, C5 | 603 | 3 | 100pF | C14858
C3 | 603 | 1 | 100nF | C14663
C6 | CAP_EEEFK1E101P | 1 | EEEFK1E101P | C178539
D1 | D_SMA | 1 | SMAJ5.0A | C908757
D2 | D_SMA | 1 | SS14 | C2480
F1 | FUSER_0ZCG0200AF2B | 1 | 0ZCG0200AF2B | C5160649
J1, J2 | JST_B6B-XH-A_LF__SN_ | 2 | B6B-XH-A_LF__SN_ | C144397
J3, J4 | PinSocket_1x19_P2.54mm_Vertical | 2 | Conn_01x19_Socket | C319202
J5 | PHOENIX_1731721 | 1 | 1731721 | C5443577
PS1 | Converter_ACDC_MeanWell_IRM-10-xx_THT | 1 | IRM-10-5 | C2857903
Q1 | SOT-23 | 1 | MMBT2222A | C7420351
R1, R5, R7 | 603 | 3 | 100k | C25803
R2, R6, R8 | 805 | 3 | 180k | C17501
R3 | 603 | 1 | 1K? | C21190
R4 | 603 | 1 | 10 K? | C15401
RV1 | B72210S0321K551 | 1 | B72210S0321K551 | C210517

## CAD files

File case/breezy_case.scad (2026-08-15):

// Breezy v4 Case
// Board: 85.05mm x 55.05mm, 2mm corner radius (measured from KiCad source)
// Mounting holes: 2.1mm (M2 hardware!), ~1.6-1.8mm inset, slightly asymmetric
// DevKit mounts vertically on the right; USB now exits the BOTTOM edge

/* [Board Dimensions] */
board_width = 85.05;
board_height = 55.05;
board_corner_radius = 2;
board_thickness = 1.6;

/* [Mounting Holes] */
hole_diameter = 2.1;  // v4 boards; v3 was 3.2/M3
standoff_height = 5;
standoff_diameter = 6;

/* [Case Parameters] */
wall_thickness = 2;
base_thickness = 2;
lid_thickness = 2;
clearance = 0.5;  // tolerance around board (FDM pockets print smaller than modeled)
// Cavity height ABOVE the base plate - the standoffs and the board live inside
// it, so the stack-up is: 5 standoff + 1.6 board + 21.5 tallest part = 28.1mm.
// Tallest part is PS1, the Mean Well IRM-10-5 (45.7 x 25.4 x 21.5 body per its
// datasheet); next are J5 at 13.8mm (Phoenix GMKDS 3/2-7,62 "constructional
// height") and the socketed DevKit at ~13mm. 30 leaves ~2mm over the PSU.
// Was 35 - an unmeasured guess. To go lower than this, the only part in the
// way is PS1: a closed blister in the lid over its 45.7 x 25.4 footprint would
// allow ~22mm here. Do NOT cut an opening there instead - that is the mains
// section (J5, RV1, AC traces).
internal_height = 30;

/* [Cutouts - positions measured from v4 KiCad board] */
// All X centres below are pad-span centres read out of the KiCad board, NOT
// footprint anchors - see the J5 note. x_offset = centre - width/2, measured
// from the board's left edge.
//
// J1/J2/USB are TOP-OPEN SLOTS running from the board surface to the top of
// the wall, so their heights are not parameters at all. The first print had
// them as fixed-height windows and all three came out too low: the JST headers
// are B6B-XH-A (vertical/top-entry, so the cable leaves upward) and the DevKit
// USB sits ~10mm up on its 1x19 sockets, neither of which a window starting at
// board level allows for. A slot cannot be too short, the board still drops
// straight in with cables attached, and the lid closes over the top.

// J1 JST connector (top edge), pad-span centre x = 30.43.
// 17 wide, not 18, purely to leave a 1.0mm wall between this and the AC
// window next door - these two are the only pair close enough to collide.
j1_width = 17;
j1_x_offset = 21.93;

// J2 JST connector (bottom edge), pad-span centre x = 30.24
j2_width = 18;
j2_x_offset = 21.24;

// AC screw terminal (top edge, left side), Phoenix GMKDS 3/2-7,62.
// Its pads are at x 8.12 and 15.74, so the body centre is 11.93 - but the
// KiCad footprint ANCHOR is at 19.55, the body's right edge. The first print
// used the anchor as the centre, putting the window 7.62mm (one pole pitch)
// off and leaving only one terminal reachable. Body is 15.24 x 13.8 tall.
// Kept as a closed window rather than a slot: this is the mains entry.
// Width 18 (not 16): the body is 15.24 wide, and FDM pockets print smaller
// than modelled, so 16 left only 0.38mm a side - too tight, same mistake as
// the 0.3mm board clearance on the first tray.
ac_width = 18;
ac_height = 15;      // body is 13.8 above the board; a little over
ac_x_offset = 2.93;  // centre 11.93

// USB port (bottom edge - the DevKit's USB faces down)
// DevKit bay spans x 55.7-84.7; sockets J3/J4 at 57.44 and 82.89 -> centre 70.2
usb_width = 14;
usb_x_offset = 63.2;

/* [DevKit Antenna Relief] */
// The DevKit is 55mm long and the board is 55.05mm tall, so the DevKit sits
// flush with the board's top and bottom edges - there is no margin anywhere
// for the WROOM module to overhang into. And it must overhang: Espressif
// requires no PCB under the antenna (FR4 detunes it), so the module hangs off
// the DevKit's top edge, past the board outline and into the wall. Without
// this relief the lid does not close (found the hard way, first print).
// The bulge runs the full height of the wall, so the board still drops
// straight in and lifts straight out - it is NOT an enclosed window.
// 2mm of plastic is transparent at 2.4GHz, so no opening is needed; air
// around the antenna is better RF than plastic against it either way.
antenna_relief = true;
relief_depth = 8;    // how far the cavity extends past the board edge (+Y).
                     // Generous: the true overhang differs between the
                     // official DevKitC and clones, and was not measured.
relief_width = 29;   // along X = exactly the DevKit bay (x 55.7-84.7). Wider
                     // than this and the outer bulge oversteps the case side,
                     // because the bay ends 0.35mm from the board edge.
relief_x = 70.2;     // bay centre from the board's left edge (= USB centre)

/* [Pegs] */
// Locating pegs instead of M2 screws - the case is mounted flat, so the board
// only needs locating, not clamping. Pegs sit below the DevKit (peg top 11mm,
// DevKit underside ~17mm on its sockets), so they do not foul it.
use_pegs = true;
peg_diameter = 1.7;  // under the board's 2.1mm hole; tapered tip to insert
peg_height = 4;      // above the standoff

/* [Rendering] */
$fn = 32;
show_base = true;
show_lid = true;
explode = 15;  // set to 0 for assembled view

// Calculated dimensions
case_width = board_width + 2*wall_thickness + 2*clearance;
case_height = board_height + 2*wall_thickness + 2*clearance;
case_internal_width = board_width + 2*clearance;
case_internal_height = board_height + 2*clearance;

// Z landmarks. board_top is the PCB's upper face - connectors sit ON it, so
// every cutout starts there, not at the cavity floor. Forgetting the standoffs
// and the board thickness is what put the first print's windows too low.
board_top = base_thickness + standoff_height + board_thickness;  // 8.6
wall_top  = base_thickness + internal_height;                    // 32

// Slots are open at the top, so raising their floor is what shortens them.
// slot_rise trims 10mm off the opening (2026-08-04, after the second print):
// nothing needs to pass through the wall down at board level - the JST cables
// leave their vertical headers upward, and the DevKit's USB rides ~10mm up on
// its sockets - so the lower 10mm was open wall for no reason.
slot_rise = 10;
slot_z    = board_top - 0.5 + slot_rise;   // 18.1
slot_h    = wall_top - slot_z + 1;         // ...up through the top of the wall

// The AC window does NOT share slot_z. It is a fixed-height window sitting on
// the terminal body (8.6..22.4 above the floor), and its height was confirmed
// correct on the first print - raising it with the slots would have put it
// almost entirely above the connector.
ac_z = board_top - 0.5;                    // 8.1

// Mounting hole positions (from board origin, x from left / y from bottom)
// Explicit coordinates measured from the v4 KiCad board - insets vary
// 1.56-1.82mm between corners, so no computed inset.
holes = [
    [1.81, 1.82],   // bottom-left
    [83.29, 1.72],  // bottom-right
    [1.75, 53.30],  // top-left
    [83.41, 53.49]  // top-right
];

module rounded_rect(w, h, r) {
    offset(r) offset(-r) square([w, h], center=true);
}

// Antenna relief footprints. The inner one extends the cavity past the board
// edge; the outer one is bigger by a wall thickness on the three exposed sides
// so the shell still wraps it. Both overlap the main body by 1mm so the union
// and difference are clean.
module relief_inner_2d() {
    y0 = case_internal_height/2 - 1;
    y1 = case_internal_height/2 + relief_depth;
    translate([relief_x - board_width/2, (y0 + y1)/2])
        square([relief_width, y1 - y0], center=true);
}

module relief_outer_2d() {
    y0 = case_internal_height/2 - 1;
    y1 = case_internal_height/2 + relief_depth + wall_thickness;
    translate([relief_x - board_width/2, (y0 + y1)/2])
        square([relief_width + 2*wall_thickness, y1 - y0], center=true);
}

// Outer footprint of the case at any Z: the rounded body plus the bulge.
module case_outline_2d() {
    union() {
        rounded_rect(case_width, case_height, board_corner_radius + wall_thickness);
        if (antenna_relief) relief_outer_2d();
    }
}

module peg() {
    cylinder(h=peg_height - 1, d=peg_diameter);
    translate([0, 0, peg_height - 1])
        cylinder(h=1, d1=peg_diameter, d2=peg_diameter - 0.6);
}
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

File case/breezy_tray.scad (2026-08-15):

// Breezy v4 Tray
// Shallow tray to hold board and protect from 220V contacts
// Board: 85.05mm x 55.05mm, 2mm corner radius (v4, measured from KiCad source)
// NOTE: v4 mounting holes are 2.1mm (not 3.2mm as in v3)

/* [Board Dimensions] */
board_width = 85.05;
board_height = 55.05;
board_corner_radius = 2;
board_thickness = 1.6;

/* [Mounting Holes] */
hole_diameter = 2.1;  // v4 boards; v3 was 3.2
standoff_height = 5;
standoff_diameter = 6;

/* [Pegs] */
use_pegs = true;
peg_diameter = 1.7;  // slightly under 2.1mm hole; fragile at this size -
                     // if pegs snap, set use_pegs=false and use M2 screws
peg_height = 4;      // above standoff

/* [Tray Parameters] */
wall_thickness = 2;
base_thickness = 2;
wall_height = 8;  // low walls, just enough to hold board
clearance = 0.5;  // FDM pockets print smaller than modeled; 0.3 was too tight

/* [Rendering] */
$fn = 32;

// Calculated dimensions
tray_width = board_width + 2*wall_thickness + 2*clearance;
tray_height = board_height + 2*wall_thickness + 2*clearance;

// Mounting hole positions (from board origin, x from left / y from bottom)
// Explicit coordinates measured from the v4 KiCad board - the four holes are
// NOT perfectly symmetric (insets vary 1.56-1.82mm), so no computed inset.
holes = [
    [1.81, 1.82],
    [83.29, 1.72],
    [1.75, 53.30],
    [83.41, 53.49]
];

module rounded_rect(w, h, r) {
    offset(r) offset(-r) square([w, h], center=true);
}

module peg() {
    // straight shank + tapered tip for lead-in
    cylinder(h=peg_height - 1, d=peg_diameter);
    translate([0, 0, peg_height - 1])
        cylinder(h=1, d1=peg_diameter, d2=peg_diameter - 0.6);
}

module tray() {
    difference() {
        union() {
            // Base plate
            linear_extrude(base_thickness) {
                rounded_rect(tray_width, tray_height, board_corner_radius + wall_thickness);
            }

            // Low walls
            linear_extrude(base_thickness + wall_height) {
                difference() {
                    rounded_rect(tray_width, tray_height, board_corner_radius + wall_thickness);
                    rounded_rect(board_width + 2*clearance, board_height + 2*clearance, board_corner_radius);
                }
            }

            // Standoffs
            for (hole = holes) {
                translate([hole[0] - board_width/2, hole[1] - board_height/2, base_thickness]) {
                    cylinder(h=standoff_height, d=standoff_diameter);
                }
            }

            // Pegs on standoffs
            if (use_pegs) {
                for (hole = holes) {
                    translate([hole[0] - board_width/2, hole[1] - board_height/2, base_thickness + standoff_height]) {
                        peg();
                    }
                }
            }
        }

        // Orientation notch in the wall top, aligned with the AC screw terminal
        // (J5). Insert the board with its screw terminal at the notch - the
        // mounting holes are slightly asymmetric, so 180° insertion binds.
        translate([19.6 - board_width/2 - 2, board_height/2 + clearance - 0.01,
                   base_thickness + wall_height - 1.5]) {
            cube([4, wall_thickness + 2, 3]);
        }

        // Screw holes (only if not using pegs)
        if (!use_pegs) {
            for (hole = holes) {
                translate([hole[0] - board_width/2, hole[1] - board_height/2, -1]) {
                    cylinder(h=base_thickness + standoff_height + 2, d=2.5);
                }
            }
        }
    }
}

tray();

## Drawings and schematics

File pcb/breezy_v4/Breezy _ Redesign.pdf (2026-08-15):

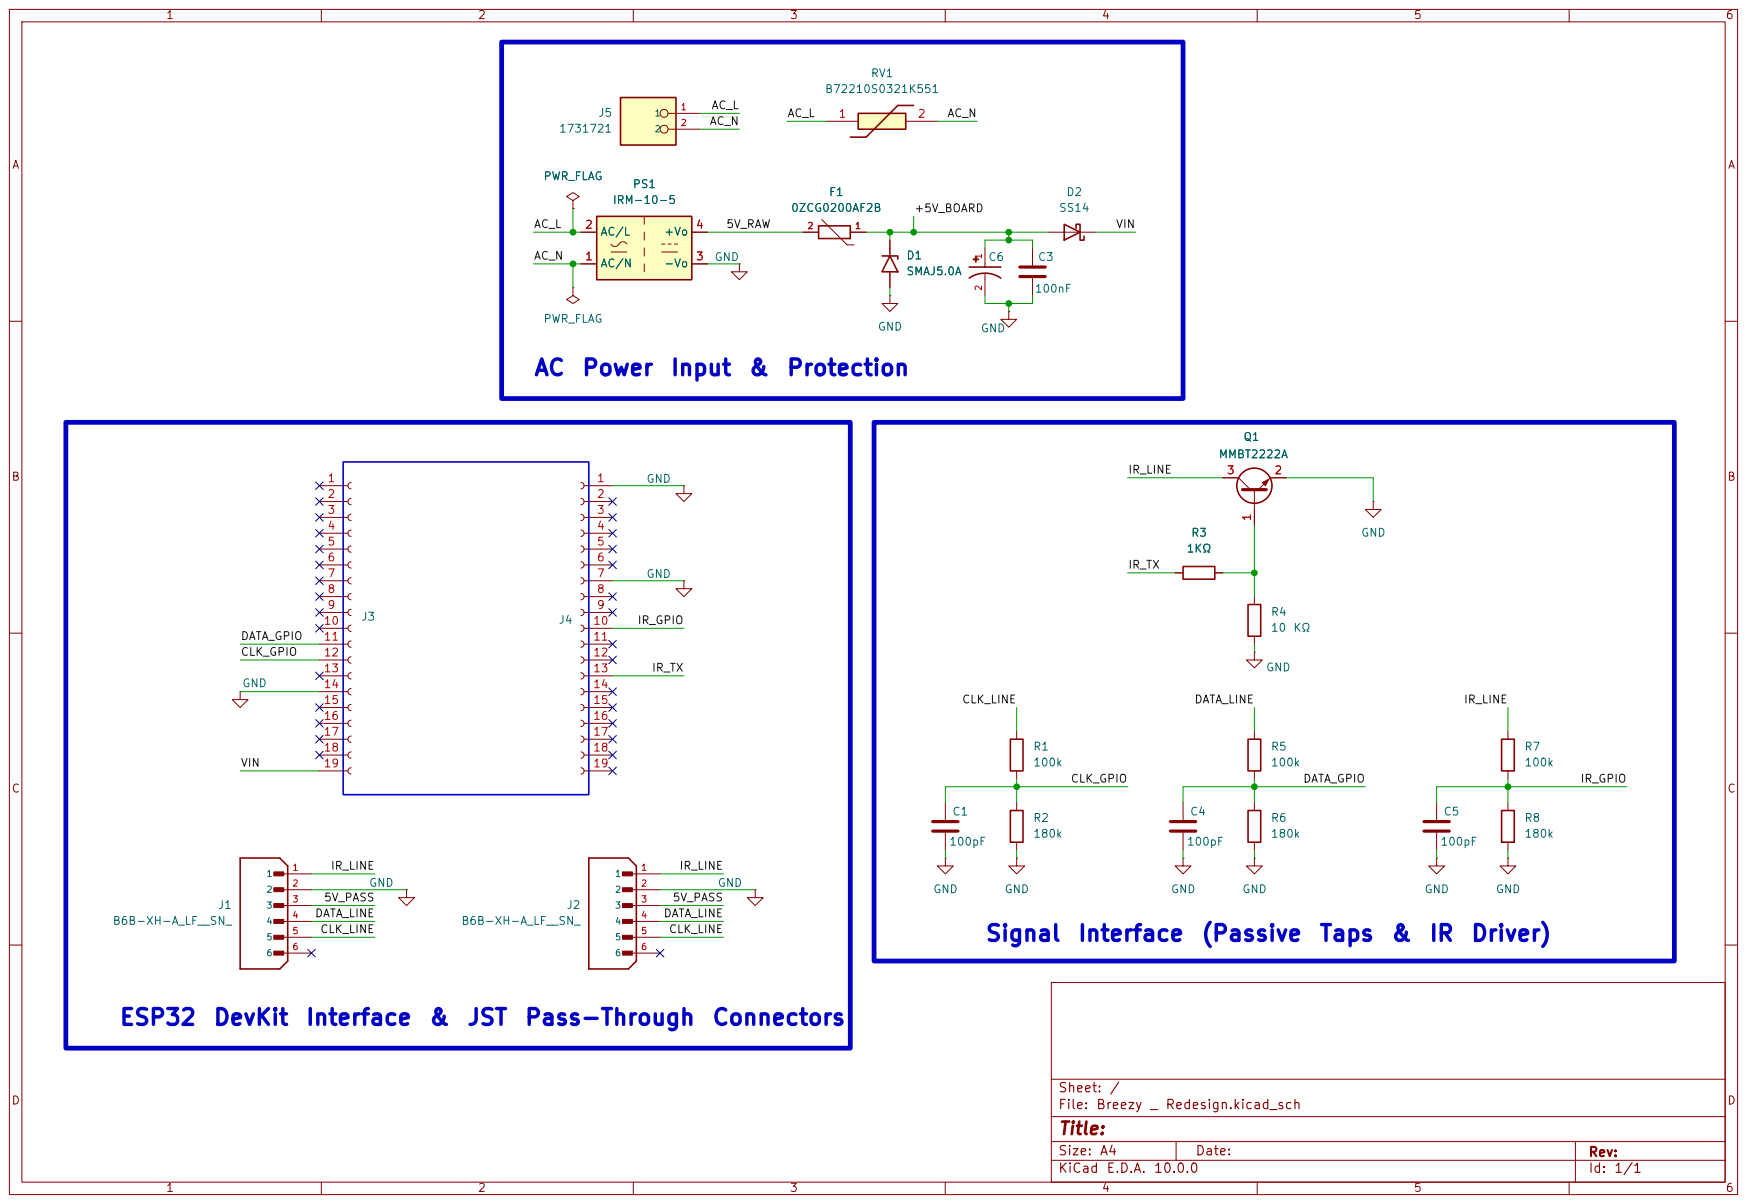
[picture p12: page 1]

GND
Signal Interface (Passive Taps & IR Driver)

ESP32 DevKit Interface & JST Pass-Through Connectors

Size: A4 | Rev:
KiCad E.D.A. 10.0.0 | Id: 1/1

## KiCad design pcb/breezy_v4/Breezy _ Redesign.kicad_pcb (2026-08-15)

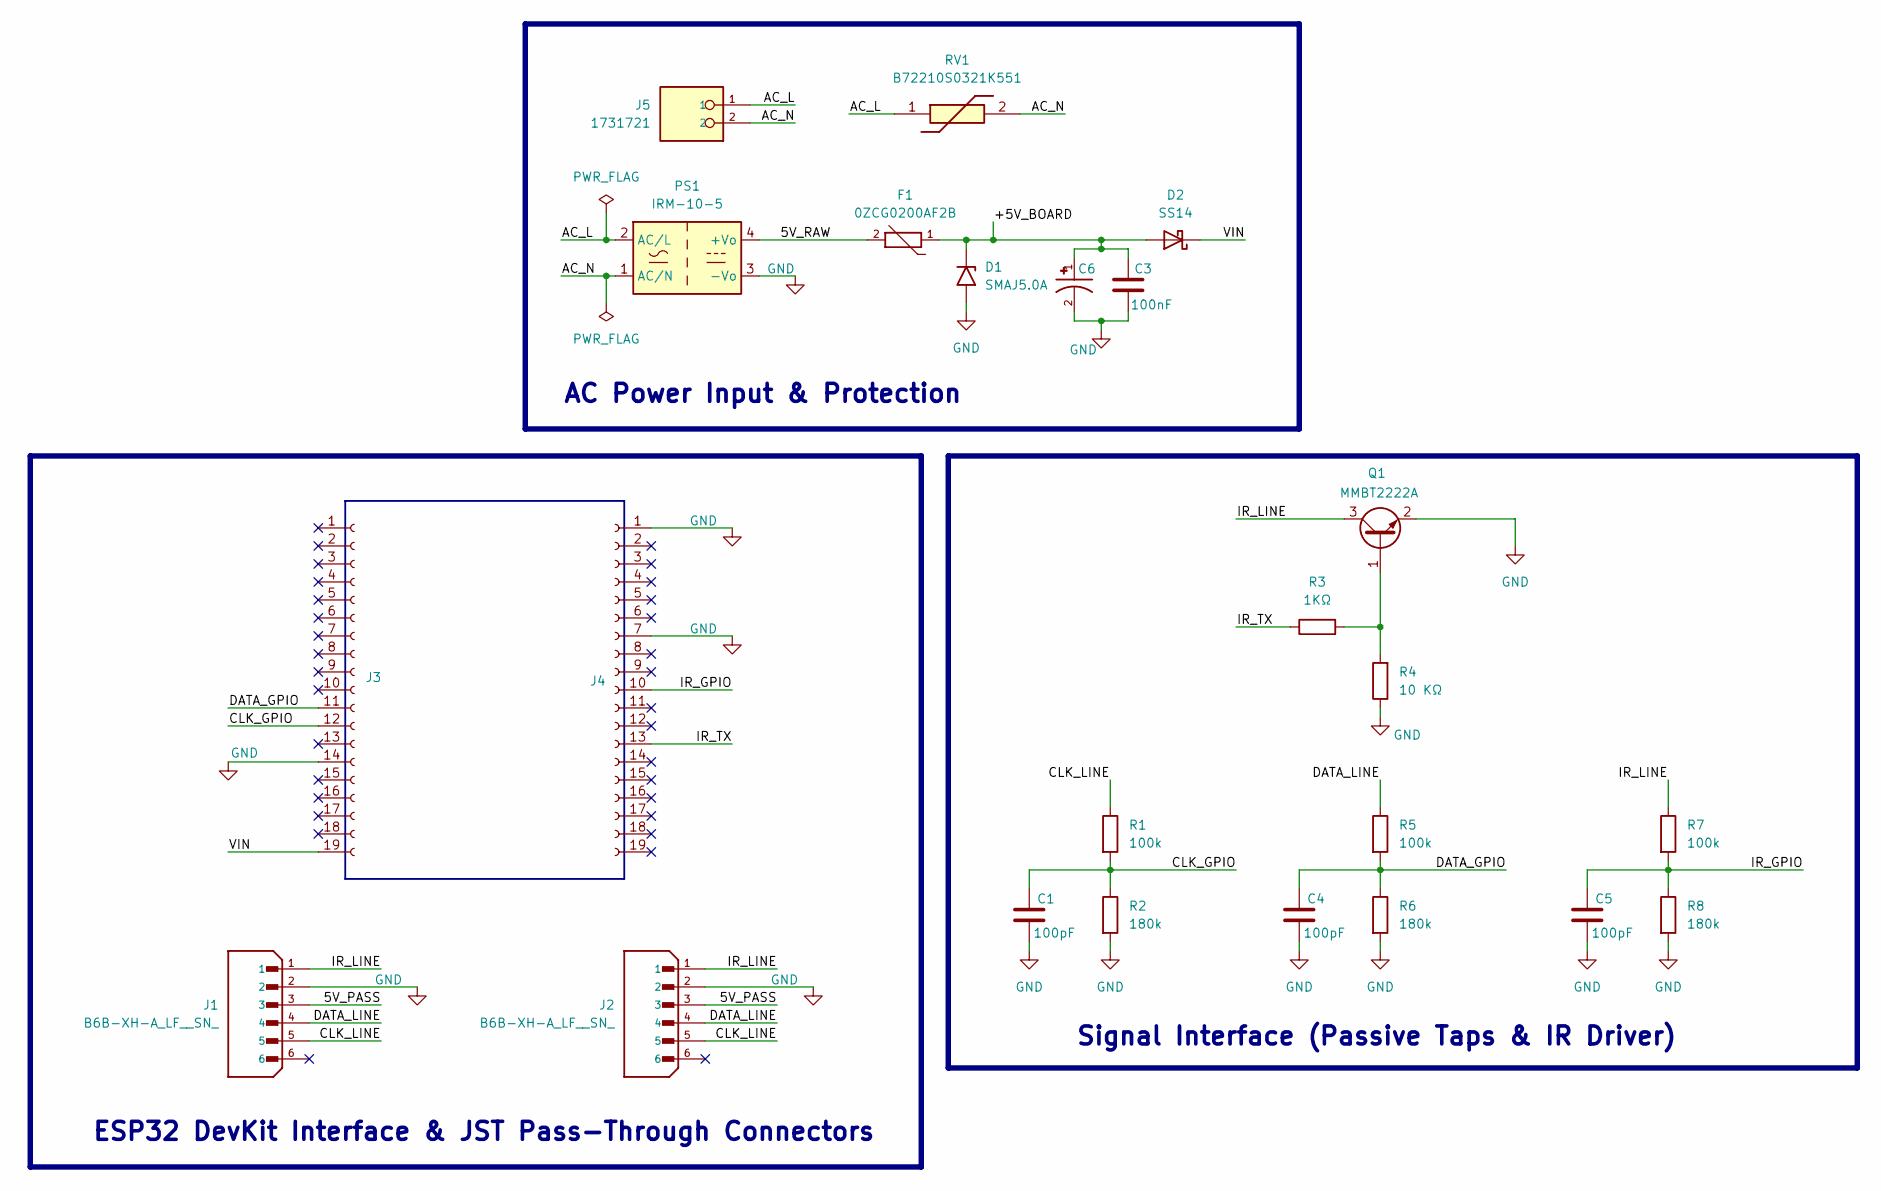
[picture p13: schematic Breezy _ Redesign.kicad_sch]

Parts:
C1, C4, C5: 100pF; C_0603_1608Metric
C3: 100nF; C_0603_1608Metric
C6: EEEFK1E101P; CAP_EEEFK1E101P; PARTREV 10-Oct-19
D1: SMAJ5.0A; D_SMA
D2: SS14; D_SMA
F1: 0ZCG0200AF2B; FUSER_0ZCG0200AF2B; PARTREV Apr2023
J1, J2: B6B-XH-A_LF__SN_; JST_B6B-XH-A_LF__SN_; PARTREV 7/4/21
J3, J4: Conn_01x19_Socket; PinSocket_1x19_P2.54mm_Vertical
J5: 1731721; PHOENIX_1731721; PARTREV 16.05.2018
PS1: IRM-10-5; Converter_ACDC_MeanWell_IRM-10-xx_THT
Q1: MMBT2222A; SOT-23
R1, R5, R7: 100k; R_0603_1608Metric
R2, R6, R8: 180k; R_0805_2012Metric
R3: 1KΩ; R_0603_1608Metric
R4: 10 KΩ; R_0603_1608Metric
RV1: B72210S0321K551; Manufacturer_Part_Number B72210S0321K551; Mouser Part Number 871-B72210S0321K551

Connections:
/5V_PASS: J1.3, J2.3
/5V_RAW: F1.2, PS1.4 (+Vo)
/+5V_BOARD: C3.1, C6.1, D1.1 (A1), D2.2 (A), F1.1
/AC_L: J5.1, PS1.2 (AC/L), RV1.1
/AC_N: J5.2, PS1.1 (AC/N), RV1.2
/CLK_GPIO: C1.1, J3.12, R1.2, R2.1
/CLK_LINE: J1.5, J2.5, R1.1
/DATA_GPIO: C4.1, J3.11, R5.2, R6.1
/DATA_LINE: J1.4, J2.4, R5.1
/IR_GPIO: C5.1, J4.10, R7.2, R8.1
/IR_LINE: J1.1, J2.1, Q1.3 (C), R7.1
/IR_TX: J4.13, R3.1
/VIN: D2.1 (K), J3.19
GND: C1.2, C3.2, C4.2, C5.2, C6.2, D1.2 (A2), J1.2, J2.2, J3.14, J4.1, J4.7, PS1.3 (-Vo), Q1.2 (E), R2.2, R4.1, R6.2, R8.2
unnamed: Q1.1 (B), R3.2, R4.2

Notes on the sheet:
ESP32 DevKit Interface & JST Pass-Through Connectors
Signal Interface (Passive Taps & IR Driver)
AC Power Input & Protection

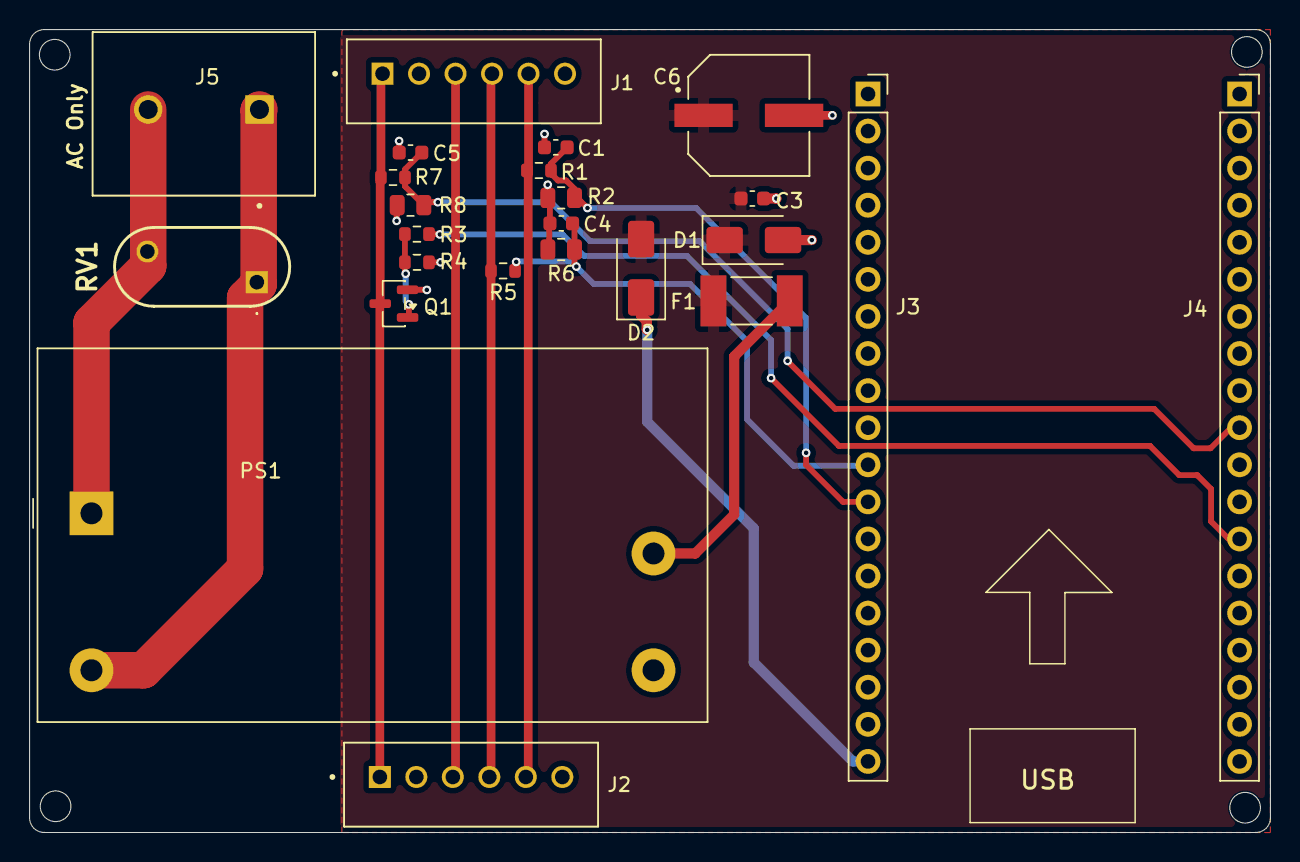
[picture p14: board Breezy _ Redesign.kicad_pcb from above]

Board: 2 copper layers, 85.0 x 55.0 mm, 24 parts (0 on the bottom side), 15 nets.

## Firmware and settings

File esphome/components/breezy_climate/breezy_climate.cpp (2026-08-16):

#include "breezy_climate.h"
#include "esphome/core/log.h"

namespace esphome {
namespace breezy_climate {

static const char *const TAG = "breezy_climate";

// Temperature byte1 encoding (same for heat/cool/fan modes)
static const uint8_t TEMP_BYTES[15] = {
    0x0c,  // 16C
    0x18,  // 17C
    0x14,  // 18C
    0x30,  // 19C
    0x3c,  // 20C
    0x28,  // 21C
    0x24,  // 22C
    0x60,  // 23C
    0x78,  // 24C
    0x78,  // 25C (same byte as 24C, different encoding)
    0x74,  // 26C
    0x50,  // 27C
    0x5c,  // 28C
    0x48,  // 29C
    0x44,  // 30C
};

// Heat mode fan byte0 values
static const uint8_t HEAT_FAN_BYTES[4] = {0x74, 0x60, 0x5c, 0x78};  // Auto, Low, Med, High

// Cool mode fan byte0 values
static const uint8_t COOL_FAN_BYTES[4] = {0x24, 0x30, 0x3c, 0x28};

// Fan-only mode byte0 = cool_byte0 XOR 0xC0
static const uint8_t FAN_ONLY_BYTES[4] = {0xe4, 0xf0, 0xfc, 0xe8};

// Power toggle byte0 values
static const uint8_t POWER_TOGGLE_BYTES[4] = {0xf4, 0xe0, 0xdc, 0xf8};

void BreezyClimate::setup() {
  ESP_LOGCONFIG(TAG, "Setting up Breezy Climate...");

  // The pin belongs to the remote_transmitter (RMT); we never touch it
  // directly. It idles LOW, which keeps the transistor off and leaves the IR
  // line released - driving it HIGH would clamp the line to ground and kill
  // the real remote.

  // Set initial state
  this->mode = climate::CLIMATE_MODE_OFF;
  this->target_temperature = 22;
  this->fan_mode = climate::CLIMATE_FAN_AUTO;

#ifdef USE_API
  register_service(&BreezyClimate::on_send_ir_raw, "send_ir_raw", {"timings"});
  register_service(&BreezyClimate::on_send_ir_raw_n, "send_ir_raw_n",
                   {"timings", "times", "wait_us"});
#endif
}

#ifdef USE_API
void BreezyClimate::on_send_ir_raw(std::vector<int32_t> timings) {
  ESP_LOGI(TAG, "send_ir_raw: %u timings", (unsigned) timings.size());
  // Clamp out-of-range values to 0; transmit_timings_ skips zeros while still
  // flipping mark/space parity, which exactly matches the old yaml lambda
  // (including tolerating the historical 65535 end-of-capture terminator).
  std::vector<uint16_t> buf(timings.size());
  for (size_t i = 0; i < timings.size(); i++) {
    int t = timings[i];
    buf[i] = (t > 0 && t < 65535) ? (uint16_t) t : 0;
  }
  transmit_timings_(buf.data(), buf.size());
}

void BreezyClimate::on_send_ir_raw_n(std::vector<int32_t> timings, int32_t times, int32_t wait_us) {
  ESP_LOGI(TAG, "send_ir_raw_n: %u timings x%d (wait %dus)",
           (unsigned) timings.size(), times, wait_us);
  if (this->transmitter_ == nullptr) {
    ESP_LOGE(TAG, "no transmitter configured");
    return;
  }
  auto call = this->transmitter_->transmit();
  auto *data = call.get_data();
  data->set_carrier_frequency(0);
  bool mark = true;
  for (int t : timings) {
    if (t > 0 && t < 65535) {
      if (mark) {
        data->mark(t);
      } else {
        data->space(t);
      }
    }
    mark = !mark;
  }
  call.set_send_times(times);
  call.set_send_wait(wait_us);
  call.perform();
}
#endif

void BreezyClimate::loop() {
  // Send any pending IR here, in the main task. Never transmit from control():
  // that can run in the httpd task where preemption corrupts the timing.
  if (tx_stage_ != TxStage::None && (int32_t) (millis() - tx_not_before_) >= 0) {
    if (tx_stage_ == TxStage::Decide) {
      // Wait (bounded) for a FRESH POWER reading before routing. Power has
      // its own freshness clock (master-vote) - it recovers from our TX
      // poisoning later than the reply stream, and gating on reply freshness
      // caused parity-flipping toggle retries (user-diagnosed 2026-08-07).
      bool fresh = spi_hub_ != nullptr && spi_hub_->status().valid &&
                   spi_hub_->power_age_ms() < 1500;
      if (!fresh && (int32_t) (millis() - decide_deadline_) < 0) {
        tx_not_before_ = millis() + 300;
        return;
      }
      bool on = fresh ? spi_hub_->status().power : hvac_definitely_on_();
      if (tx_target_off_) {
        if (on) {
          tx_stage_ = TxStage::PowerToggle;
          tx_command_after_toggle_ = false;
        } else {
          tx_stage_ = TxStage::None;  // already off
        }
      } else {
        if (on) {
          tx_stage_ = TxStage::Command;
        } else {
          tx_stage_ = TxStage::PowerToggle;
          tx_command_after_toggle_ = true;
        }
      }
      return;
    }
    if (tx_stage_ == TxStage::PowerToggle) {
      bool state_frame = send_power_toggle_();
      if (tx_command_after_toggle_ && state_frame) {
        // Single blast: the power frame carried the full target state, so
        // there is no chaser and no wrong-mode limbo. Just verify.
        tx_stage_ = TxStage::None;
        verify_pending_ = true;
        verify_at_ = millis() + verify_wait_ms_;
      } else if (tx_command_after_toggle_) {
        // Unmapped combo fell back to the legacy toggle: chase with the full
        // command after the receptive window (measured 2026-08-03: 500ms was
        // too early, 3000ms works).
        tx_stage_ = TxStage::Command;
        tx_not_before_ = millis() + 3000;
      } else {
        // Power-off: verify it actually went off.
        tx_stage_ = TxStage::None;
        verify_pending_ = true;
        verify_at_ = millis() + verify_wait_ms_;
      }
    } else {
      send_ir_command_(tx_mode_, tx_temp_, tx_fan_);
      if (tx_bursts_left_ == 0) tx_bursts_left_ = kTxBursts;
      if (--tx_bursts_left_ > 0) {
        tx_not_before_ = millis() + kTxBurstGapMs;
      } else {
        tx_stage_ = TxStage::None;
        // The HVAC reflects an accepted command within ~1.3s and the decode
        // is fresh within ~1s, so 2.5s is a safe verify point - tightened
        // from 4s (2026-08-06) to speed the retry loop, which is the whole
        // acceptance mechanism (see tx_retries_left_).
        verify_pending_ = true;
        verify_at_ = millis() + verify_wait_ms_;
      }
    }
    return;  // skip the sensor sync this iteration; state is in flux
  }
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

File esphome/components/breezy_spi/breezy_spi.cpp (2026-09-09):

#include "breezy_spi.h"
#include "esphome/core/log.h"
#include <Arduino.h>

namespace esphome {
namespace breezy_spi {

static const char *const TAG = "breezy_spi";

// Global instance for ISR
BreezySPIComponent *global_breezy_spi = nullptr;

// Static ISR handler
static void IRAM_ATTR spi_clock_isr() {
  if (global_breezy_spi != nullptr) {
    global_breezy_spi->handle_clock_isr();
  }
}

void BreezySPIComponent::setup() {
  ESP_LOGCONFIG(TAG, "Setting up Breezy SPI...");

  global_breezy_spi = this;

  clk_pin_->setup();
  data_pin_->setup();

  // Attach interrupt on CLK rising edge using Arduino API
  attachInterrupt(digitalPinToInterrupt(clk_pin_->get_pin()), spi_clock_isr, RISING);

  ESP_LOGCONFIG(TAG, "  CLK pin: GPIO%d", clk_pin_->get_pin());
  ESP_LOGCONFIG(TAG, "  DATA pin: GPIO%d", data_pin_->get_pin());
}

// RAW BUS DIALECT (2026-08-04, reverse-engineered after the permanent install
// removed the AC's "splitter" - actually an active protocol translator that
// re-served this bus flattened into 112-bit frames; everything before that
// date was decoded downstream of it and never saw the real bus).
//
// The raw bus runs a 33ms poll/response cycle:
//   - 113-bit master frames headed 95 5F (controller -> panel)
//   - short ~36-bit polls answered after a ~611us turnaround by ~76-bit
//     replies headed 60 00 (panel -> controller)
// The replies carry the OLD dialect's fields at the OLD byte offsets with the
// OLD encodings - the splitter was re-broadcasting them nearly verbatim. So
// this ISR just records gap-delimited bursts as they are; loop() picks out
// the replies. Frame grammar and field map validated against 13 labeled
// captures + live LCD ground truth, v4_bringup_notes.md 2026-08-04.
void IRAM_ATTR BreezySPIComponent::handle_clock_isr() {
  uint32_t now = micros();
  uint32_t elapsed = now - spi_last_bit_time_;

  // DIAGNOSTIC (2026-08-14): bucket EVERY edge interval before the guard, to
  // find out whether the guard is eating real clock edges - 40% of replies
  // arrive one bit short. Decode path below is untouched.
  if (elapsed < 640) {
    edge_hist_[elapsed >> 5]++;  // 20 buckets x 32µs
  } else {
    edge_hist_[20]++;
  }

  // Debounce: real clock edges arrive every ~140µs; anything sooner is a
  // glitch. 50µs let 60-130µs runts through, causing 1-bit frame slips
  // (verified against 25k captured frames, 2026-08-02).
  if (elapsed < 90) return;
  spi_last_bit_time_ = now;

  // Gap-delimited burst recorder - no opinion about frame length; the bus has
  // 36/76/113-bit bursts and mis-guessing here is how the last decoder died.
  if (elapsed > 500) {
    if (cap_bits_ > 0) {
      uint8_t h = cap_head_;
      cap_ring_[h].gap_us = cap_gap_;
      cap_ring_[h].nbits = cap_bits_;
      uint16_t nbytes = (cap_bits_ + 7) / 8;
      for (uint16_t i = 0; i < nbytes && i < CAP_BYTES; i++)
        cap_ring_[h].data[i] = cap_cur_[i];
      cap_head_ = (h + 1) % CAP_RING;
    }
    cap_gap_ = elapsed;
    cap_bits_ = 0;
  }
  if (cap_bits_ < CAP_BYTES * 8) {
    uint16_t idx = cap_bits_ >> 3;
    if ((cap_bits_ & 7) == 0) cap_cur_[idx] = 0;
    cap_cur_[idx] |= data_pin_->digital_read() << (7 - (cap_bits_ & 7));
  }
  cap_bits_++;
}

void BreezySPIComponent::loop() {
  // Health heartbeat at DEBUG (1 line / 5s): how stale is the decoded state,
  // and how much is the slip filter rejecting. last_frame_age is the number
  // that catches a starved pipeline - the stale-witness failure mode of
  // 2026-08-04 would have been visible here in seconds instead of hours.
  uint32_t now_ms = millis();
  if (now_ms - diag_last_report_ >= 5000) {
    diag_last_report_ = now_ms;
    // uint32_t is `unsigned long` on the xtensa toolchain, so %u needs an
    // explicit cast or -Wformat warns. ESP_LOG* is format-checked too, not
    // just snprintf. Same idiom as the (unsigned) casts in breezy_climate.cpp.
    ESP_LOGD(TAG, "health: slip_rejects=%u last_frame_age=%ums",
             (unsigned) diag_slip_rejects_,
             (unsigned) (status_.valid ? now_ms - status_.timestamp : 0));
    // Inter-edge interval histogram, 32µs buckets. Cheap (one line / 5s) and
    // it is the instrument that identified log-flood frame corruption on
    // 2026-08-14: a healthy bus is bimodal - ~95% of edges in the 128-159µs
    // bucket (the real clock) and a few % of sub-32µs runts. Any population
    // appearing between those, or a collapse of the 128-159 peak, means
    // edges are being missed and frames are losing bits.
    char hb[256];
    size_t hp = 0;
    for (int i = 0; i < 21 && hp < sizeof(hb) - 16; i++) {
      if (edge_hist_[i])
        // (unsigned) for the same -Wformat reason as the log line above.
        hp += snprintf(hb + hp, sizeof(hb) - hp, "%d:%u ", i * 32,
                       (unsigned) edge_hist_[i]);
    }
    ESP_LOGD(TAG, "edges: %s", hb);
  }

  // Drain the burst ring: pick out panel replies, filter slips, vote, decode.
  while (cap_tail_ != cap_head_) {
    CapBurst b;
    b.gap_us = cap_ring_[cap_tail_].gap_us;
    b.nbits = cap_ring_[cap_tail_].nbits;
    uint16_t nbytes = (b.nbits + 7) / 8;
    if (nbytes > CAP_BYTES) nbytes = CAP_BYTES;
    for (uint16_t i = 0; i < nbytes; i++) b.data[i] = cap_ring_[cap_tail_].data[i];
    cap_tail_ = (cap_tail_ + 1) % CAP_RING;

    // TWO capture instruments, and the choice matters enormously:
    //
    // 1. THROTTLED SAMPLER (DEBUG, <=2 bursts/s) - use this one. Low enough
    //    volume that it does not disturb the ISR.
    // 2. FULL BURST STREAM (VERBOSE, every burst) - THE OBSERVER EFFECT
    //    TRAP. Logging ~100 bursts/s blocks the capture ISR long enough to
    //    miss clock edges, so frames silently LOSE BITS: everything after
    //    the drop shifts left, and a drop inside a run of zeros still looks
    //    structurally legal. Measured 2026-08-14: 40% of replies corrupted
    //    under VERBOSE vs 0.1% at DEBUG. Every "mystery frame" in this
    //    project's history came from VERBOSE-era data (the 75-bit
    //    "subtype-B", the 112-bit master variant, the bogus DRY=0x40 mode
    //    code - all shifted frames). If you must use it, treat the output
    //    as noisy and majority-vote everything.
    uint32_t sample_now = millis();
    bool sample_it = (sample_now - last_sample_ms_) >= 500;
#if ESPHOME_LOG_LEVEL >= ESPHOME_LOG_LEVEL_VERBOSE
    const bool build_hex = true;
#else
    const bool build_hex = sample_it;
#endif
    if (build_hex) {
      char hex[CAP_BYTES * 3 + 1];
      for (uint16_t i = 0; i < nbytes; i++) sprintf(hex + i * 3, "%02X ", b.data[i]);
      hex[nbytes * 3] = 0;
      ESP_LOGV(TAG, "burst: gap=%uus nbits=%u %s", b.gap_us, b.nbits, hex);
      if (sample_it) {
        last_sample_ms_ = sample_now;
        ESP_LOGD(TAG, "sample: nbits=%u %s", b.nbits, hex);
      }
    }
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

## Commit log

2026-08-15 Breezy: ESP32 bridge between an HVAC controller and its LCD panel
    Reads the controller<->panel bus (fully decoded, including the two frame
    checksums) and writes by synthesising the IR command language the vendor
    remote speaks. Exposed to Home Assistant via ESPHome.
    Contents: the v4 PCB (KiCad source + gerbers), the ESPHome components,
    a printable case, and the protocol specs in docs/.
    [Breezy _ Redesign.kicad_pcb, Breezy _ Redesign.kicad_sch, bom.csv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]
2026-08-15 Docs: note that over-long bursts are two frames glued, not corruption
    The decoder un-glues them; without this the code does something the spec
    does not explain. Also a typo fix.
2026-08-16 The isochrony law: every frame is exactly 68 ticks
    Symbols are exact multiples of a ~960us tick (SS=2 LS=3 LM=3 LL=4); code
    and temp words are fixed 18-tick waveforms; the '7-bit' oddities are one
    byte's unique second same-duration rendering, used exactly where the word
    inventory ran short. Live-confirmed with a discriminator test (identical
    bits at 66 ticks: ignored; 68 ticks: accepted). PROTOCOL_IR.md section
    3.5 has the full law, its consequences, and testable predictions.
2026-09-09 Fix the ESP-IDF build: %u on a uint32_t; add diagnostics to the example config
    breezy_spi.cpp formatted a volatile uint32_t with %u in the edge-histogram
    line. uint32_t is `unsigned long` on the xtensa toolchain, so this is a
    -Wformat violation, and the ESP-IDF build treats it as fatal. It is the only
    format-checked call in either component - every other log site goes through
    ESP_LOG*, which carries no format attribute - which is why this single line
    was the whole failure. Cast to (unsigned), matching breezy_climate.cpp.
    Verified in a container against the real ESP-IDF 5.5.5 xtensa toolchain: the
    unpatched tree reproduces the failure exactly, the patched tree links clean
    (RAM 28.3%, flash 5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
    [breezy_spi.cpp]
2026-09-09 Silence the remaining -Wformat warning; correct the comment
    The previous commit claimed the %u mismatch was fatal to the build. It is not:
    it is a warning. The build's only hard error was a missing custom_services
    flag in the deploying user's yaml, and the format warning merely sat next to
    it in the output. Line 99 settles it - that ESP_LOGD still warned after the
    snprintf was cast, and the build linked anyway. ESP_LOG* is format-checked
    too, which the earlier comment also got wrong.
    Cast the two uint32_t args on the health line, and say accurately why.
    Claude-Session: https://claude.ai/code/session_01V2YxLoM9Rct6npZB5kJbrt
    [breezy_spi.cpp]
2026-09-09 wifi: power_save_mode none on a mains-powered node
    Observed failure that motivates this: a 70-minute outage in which the node
    stayed associated the whole time (EAPOL 4-way completed repeatedly) and
    broadcast 127 DHCPDISCOVERs, every one of which the router answered with a
    DHCPOFFER - and not one DHCPREQUEST came back. Broadcast out worked, unicast
    in did not, because the AP was not delivering buffered frames to a station in
    power save. The node simply had no IP, and re-associated every 33-45s until an
    attempt happened to land.
    Other clients completed DHCP normally in the same window, and the node's RSSI
    measured -42 dBm, so neither the router nor RF was involved. ESP32 defaults to
    LIGHT; on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
2026-11-12 breezy_spi: the state-frame checksum is one byte sum, not two nibble sums
    S = (sum of nibble-reversed bytes 1..7 + (br4(byte8>>4) << 4)) mod 256;
    byte8's low nibble is br4(S & 0xF), byte9's high nibble is br4(S >> 4).
    The 2026-08-14 model (two independent mod-16 sums, constant -2 seed) was
    this formula restricted to the archive's conditions: low sums under 16
    and rooms 24-27, where byte8's high nibble is a constant 2.
    First heat use (2026-11-11) broke it: heat/25/low with the compressor
    running sums past 16, every frame was rejected for minutes, the decode
    froze on the last accepted state (OFF) and HA showed off while the unit
    ran. A carry-only fix then broke within an hour at room 22 (byte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
2026-11-12 breezy_climate: power-off frame carries the unit's live state, not Cool
    control() set this->mode = OFF before loop() built the toggle, and
    send_power_toggle_() mapped OFF to Cool, so every HA power-off sent a
    cool-spelled power frame. Correct by accident all summer; a heat unit
    ignored it 6/6 on 2026-11-12 with the decode fresh throughout. The off
    frame now takes mode/fan/set from the live SPI decode, falling back to a
    snapshot of the entity state taken before it is overwritten. The log line
    names the direction and the spelled mode.
    Full on/off matrix after flashing: 12 wakes, 12 offs, heat-idle wake and
    off, 26/26, one frame per step, zero retries.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
